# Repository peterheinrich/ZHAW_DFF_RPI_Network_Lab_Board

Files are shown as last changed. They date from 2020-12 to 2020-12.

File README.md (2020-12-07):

# RPI Hands on Networking Lab Board

## Project status: Proof-of-Concept (PoC) success
## !!! THIS IS JUST A PoC !!! Use the provided material and documentation at your own risk!
Known problems:
* The two SATA connectors are a little too close together. While two disks still barely fit, there should be more space in future version.

# General Overview
Welcome to the Git repository of a Raspberry Pi (Compute Module) based networking educational board. Its core features include:
* Three 10/100 Ethernet ports
* A total of 7 USB 2.0 ports:
  * 2x at the front for WiFi adapters
  * 3x internal for USB Drives (simulating RAID 0/1/5)
  * 2x at the back for keyboard and mouse
* Two SATA ports for larger storage (Raid 1)
* Single 12V@2A system supply
* Flexible boot options (SD-Card, USB, Network)
* Raspberry-Pi 40 pin header and mounting options for standard RPI-Hats
* DSI display connector with the same pinout as on Rasperry-Pi-3B boards
* HDMI connector (HDMI out) for external monitors
* CP2102 serial console over USB (microusb device connector) RxD/TxD only!
* ATMega328 (Arduino compatible) system management controller:
  * Power supply monitoring and control (power rail sequencing)
  * System reboot coordination
  * Bootmode selection
  * LVTTL (3.3V) uart for automatic (i.e. remote) board management

Although all peripherals share a single USB2.0 bus and will hence be "slow" to some degree, it should not hamper the learning outcome. 
The purpose of these boards is to provide a self-contained lab environment rather than being small servers. However, in environments where 
speed is not of primary concern, such a system (or systems) could still make a valuable contribution. 

# Fully Open Source / Open Hardware
Everything in this repository is licensed under permissive open source / open hardware licenses.
* License for hardware design documentes (SEE LICENSE_Hardware file): <strong>CERN Open Hardware Licence Version 2 - Permissive</strong>
* License for firmware (SEE LICENSE_Software file): <strong>2-Clause BSD License</strong> 

# Prototype REV-B
SUCCESS! The REV-B prototype is fully operational. Network, display with touch, SATA and all the USB ports are working properly.
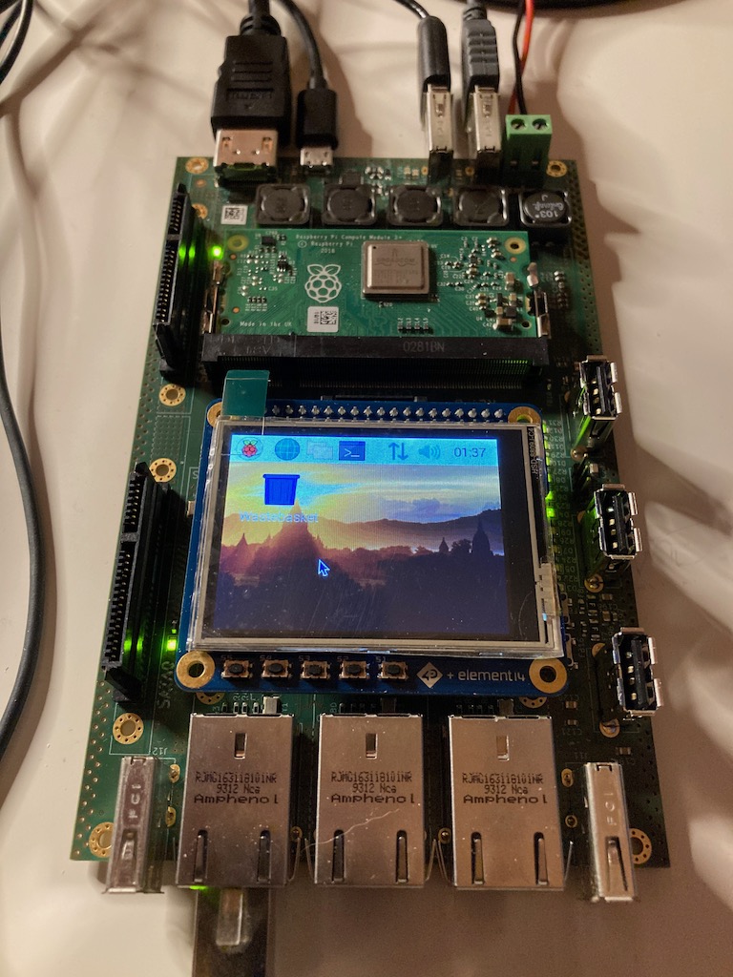
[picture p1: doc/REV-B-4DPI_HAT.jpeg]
Final System With HAT

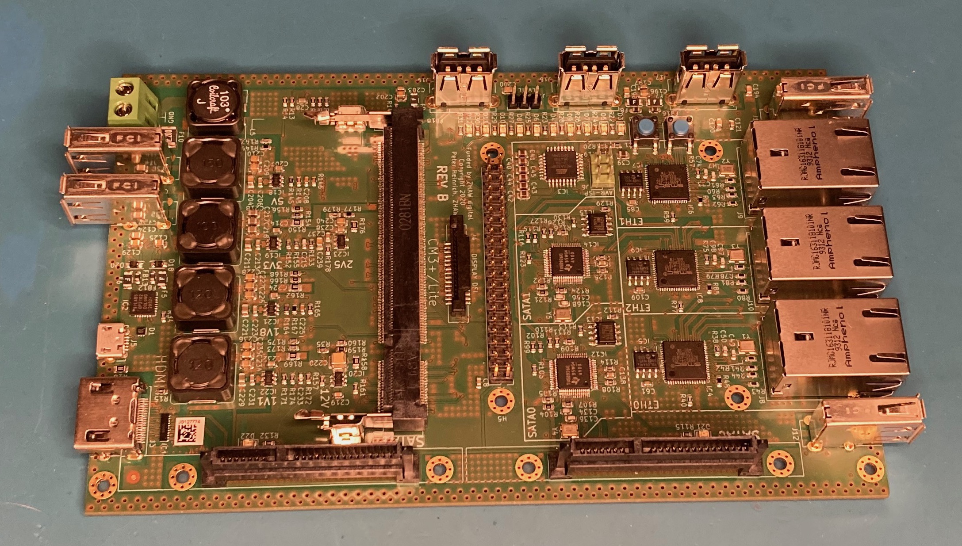
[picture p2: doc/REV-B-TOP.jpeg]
TOP

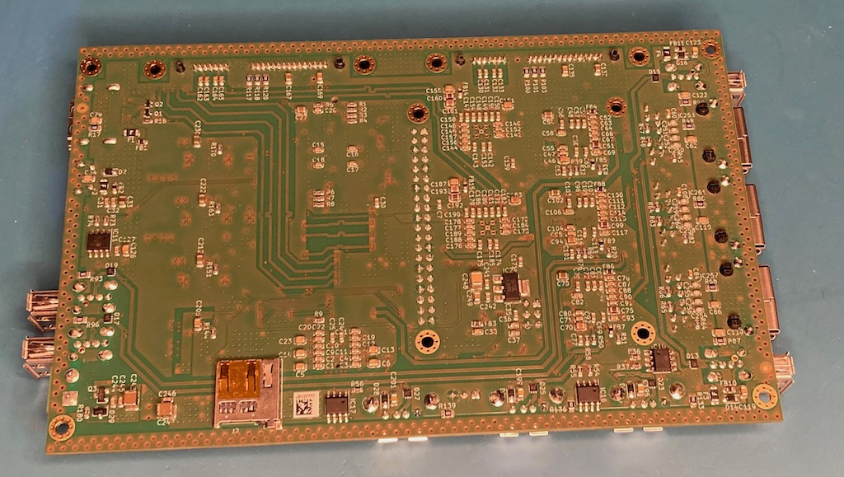
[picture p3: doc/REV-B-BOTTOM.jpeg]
BOTTOM


### System Architecture
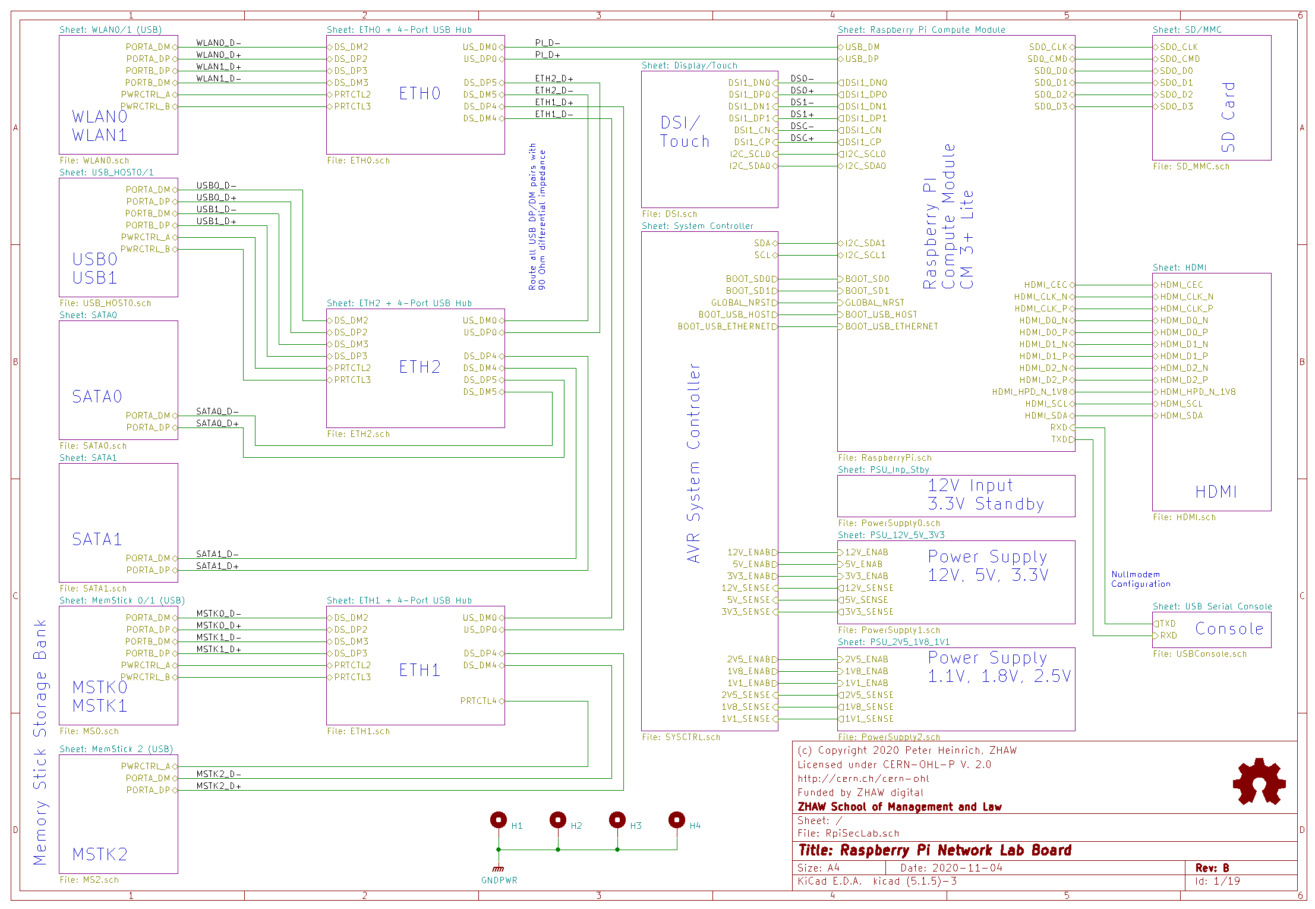
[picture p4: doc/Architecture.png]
Architecture Overview

### Initial PCB Artwork
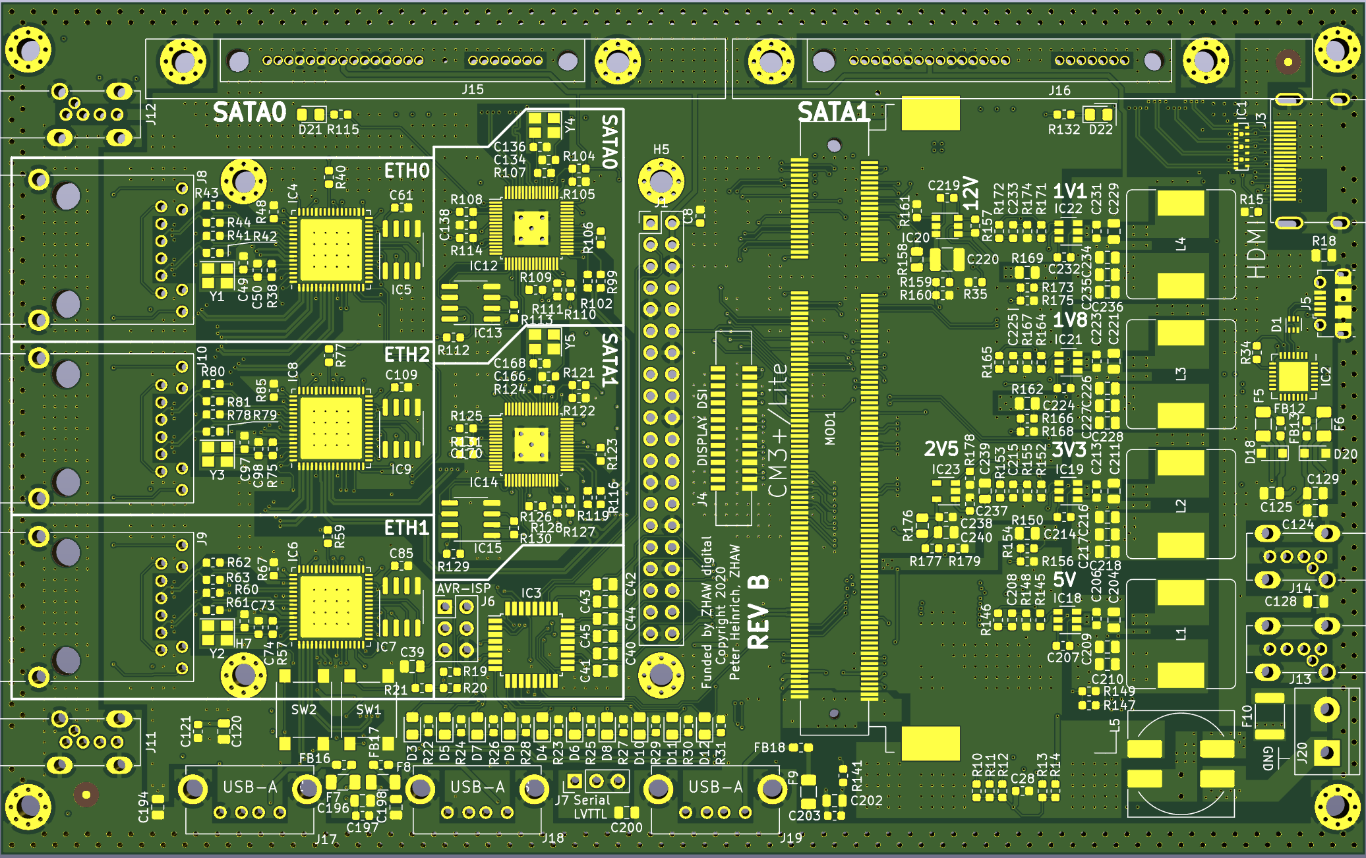
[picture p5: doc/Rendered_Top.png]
PCB Artwork TOP

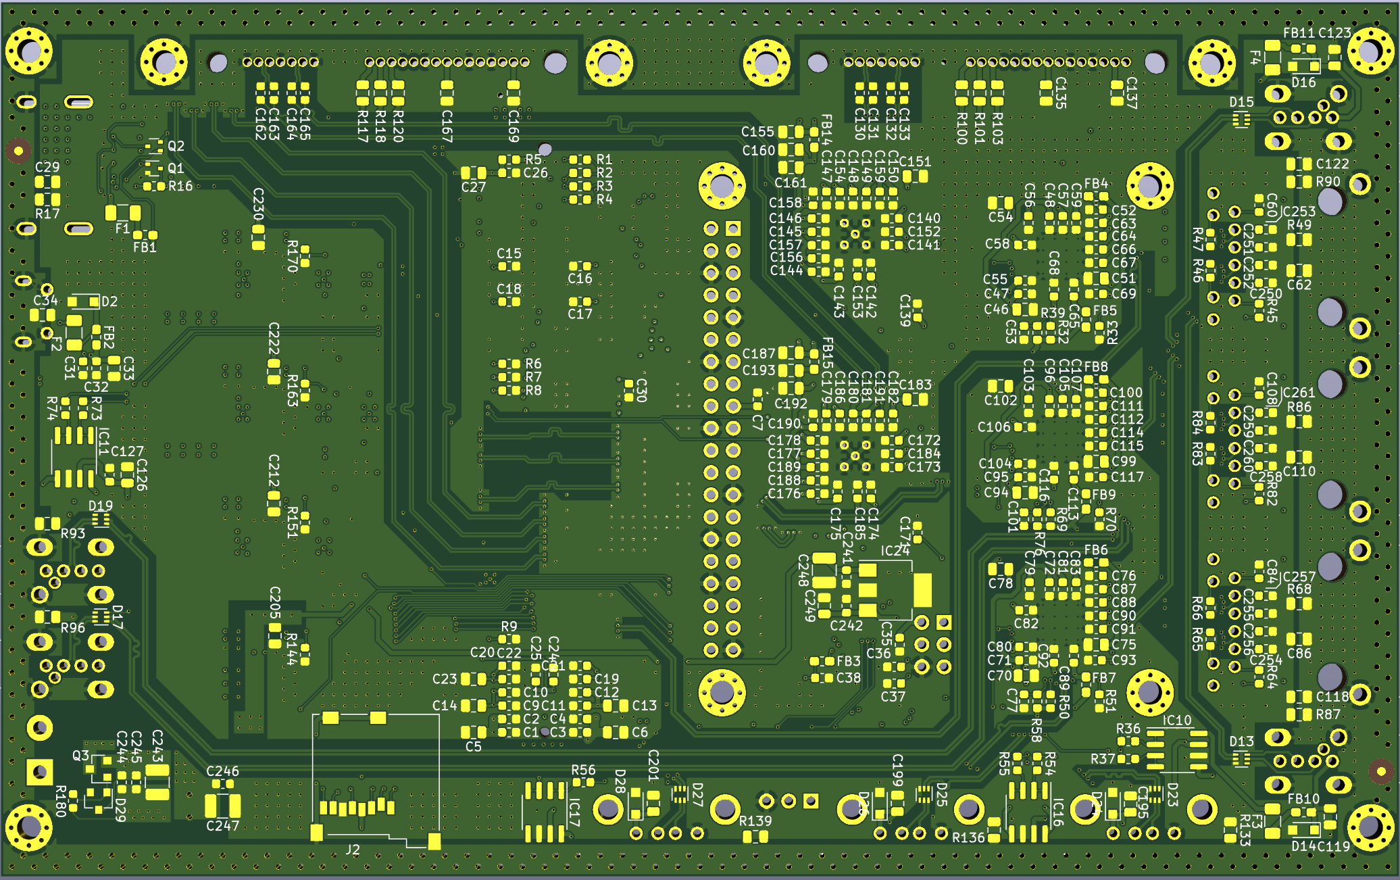
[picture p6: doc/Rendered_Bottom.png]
PCB Artwork BOTTOM


## Prototype REV-A
The project successfully surpassed the revision A proof-of-concept. While its documentation is not included in the repository anymore,
here are some images documenting this project phase:

First time booting Raspbian ...
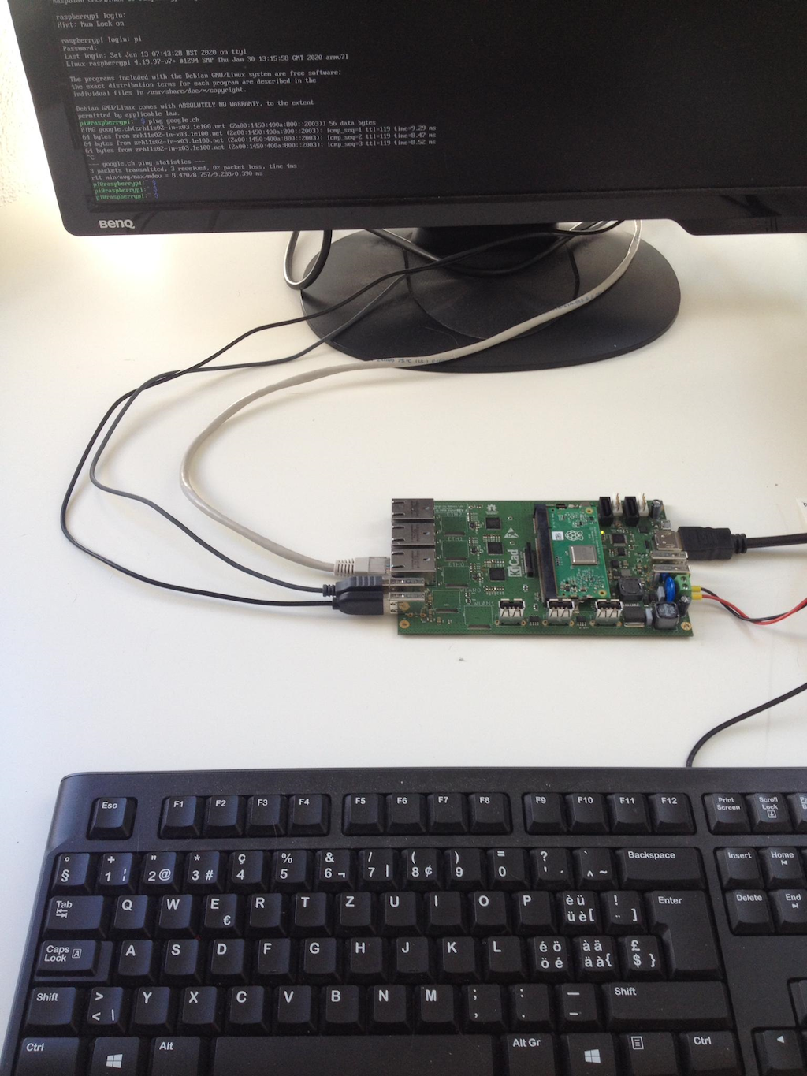
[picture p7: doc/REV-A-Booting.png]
REV-A board booging

Some debugging of network and SATA ...
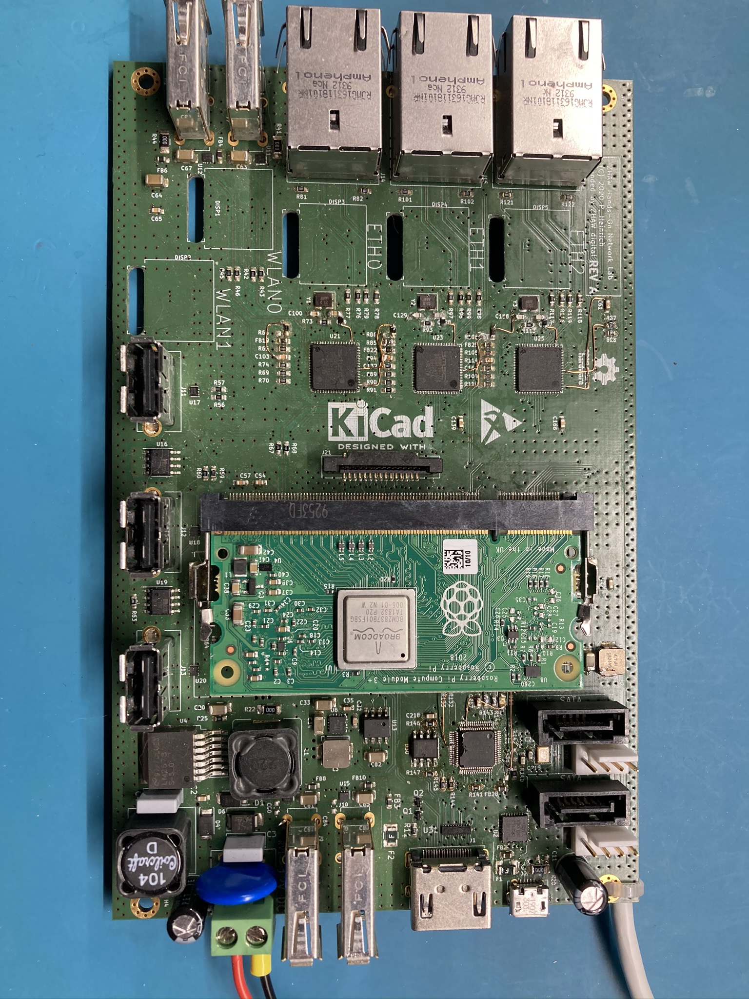
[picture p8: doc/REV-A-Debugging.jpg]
REV-A board debugging

First time successful SATA disk access after finding out that the TI SATA controller only works with some SPI flash chips (i.e. the ones that allow 128 byte page writes with command 0x02).
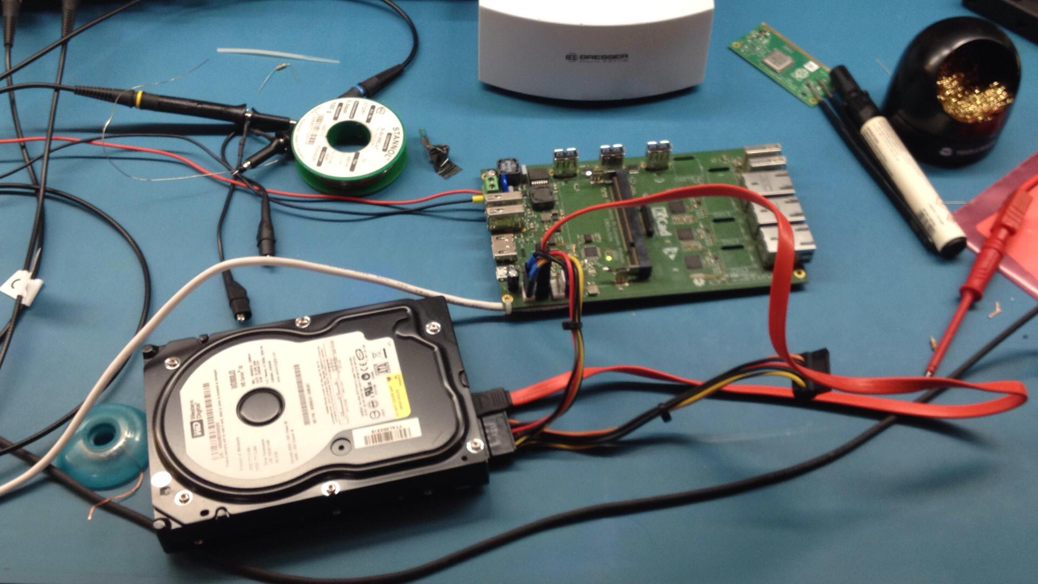
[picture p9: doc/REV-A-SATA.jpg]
REV-A board SATA


# Scenarios
Currently scenarios are developed and will be supplied here later. The initial demonstration scenarios will include:
## Raid Lab
With a single board, students will explore the setup of different raid levels and their behavior under different fault conditions. 
Experiments could cover:
  * Different RAID levels (0/1/5) or even RAID 10 using an additional USB port.
  * Hot spares
  * LVM/LUKS setups
  * System behaviour when disks fail

## HA-Lab
Using three boards, students explore basic high availability concepts.
Experiments could cover:
  * DRBD disk synchronization and cluster file systems
  * Samba active/active setups
  * MySQL active/active replication
  * Round robin DNS load balancing
  
## MitM-Lab (Man-in-the-Middle)
Using three boards students can simulate a two-party communication and an attacker that can eavesdrop / alter the communication.
Experiments could include:
  * ARP spoofing
  * DNS spoofing
  * SSL encryption
  * Mitigation concepts (such as certificate pinning)

## Firewall/IDS-Lab
Using three boards, a typical small firewall setup with an internal and a DMZ zone can be modeled. Students will explore basic
iptables / nftables filtering (IPv4/IPv6), nat (IPv4) setups.

# Acknowledgements
This project received funding from ZHAW digital.

Special thanks to Mirjam Blumenstein, Peter Berlich and Christian Weber for working on the specification and application scenarios. Many thanks to Sami Kjazimi for reviewing my design files and answering my endless questions on electronics design :-)

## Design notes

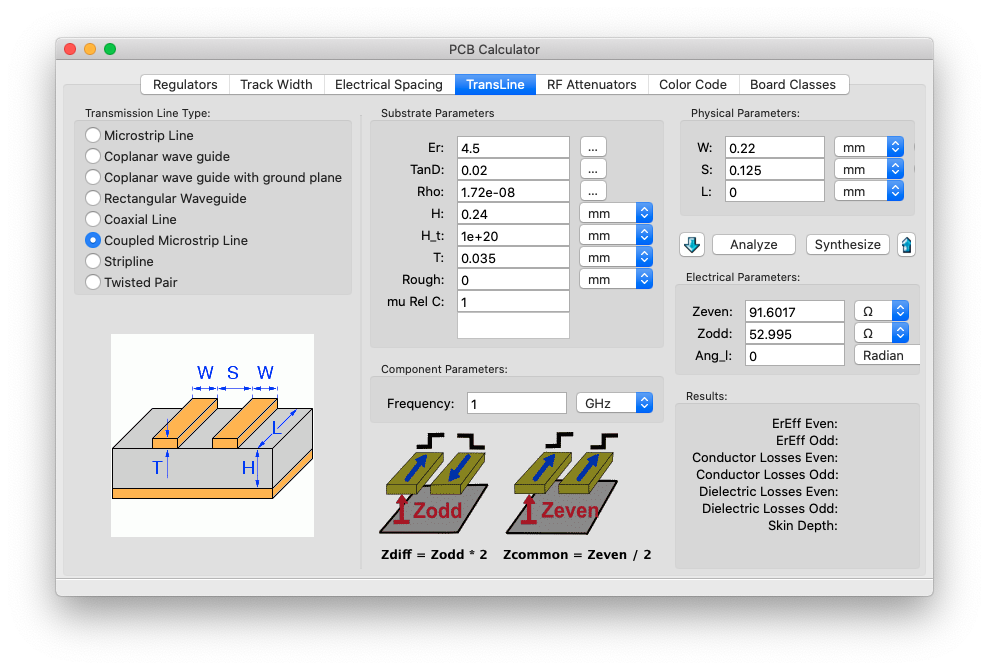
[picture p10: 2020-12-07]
design/100-Ohm-Impedance.png

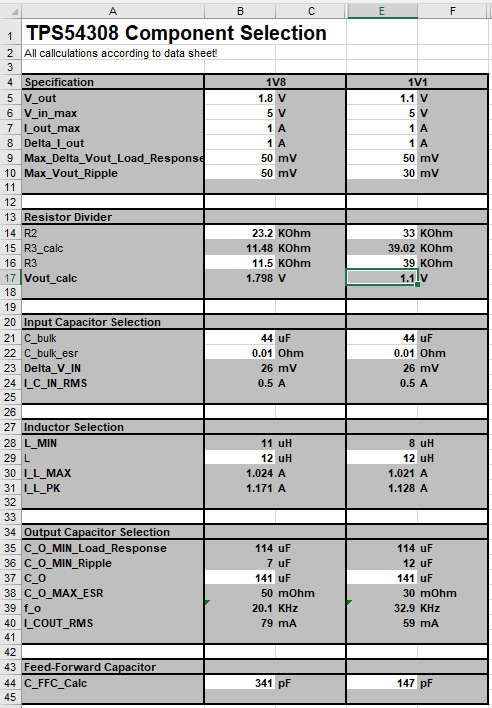
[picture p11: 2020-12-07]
design/TPS54308_1V8_1V1_Calculations.PNG

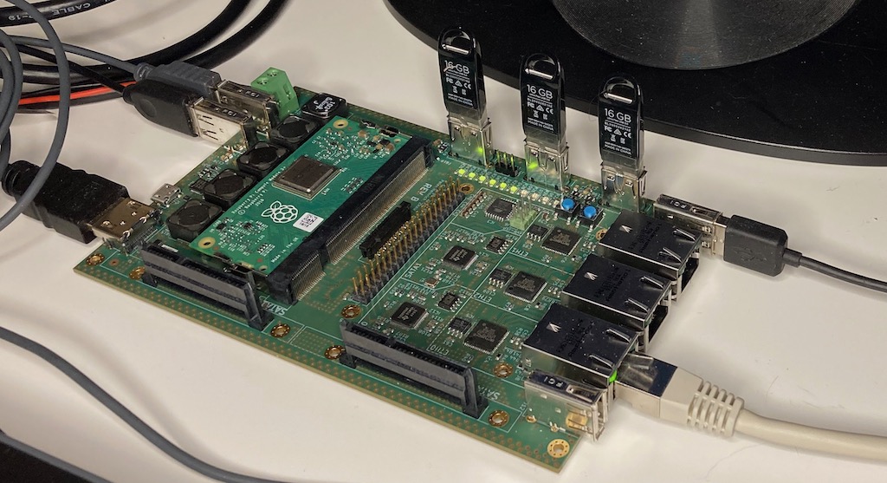
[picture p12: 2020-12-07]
doc/REV-B-DEMO.jpeg

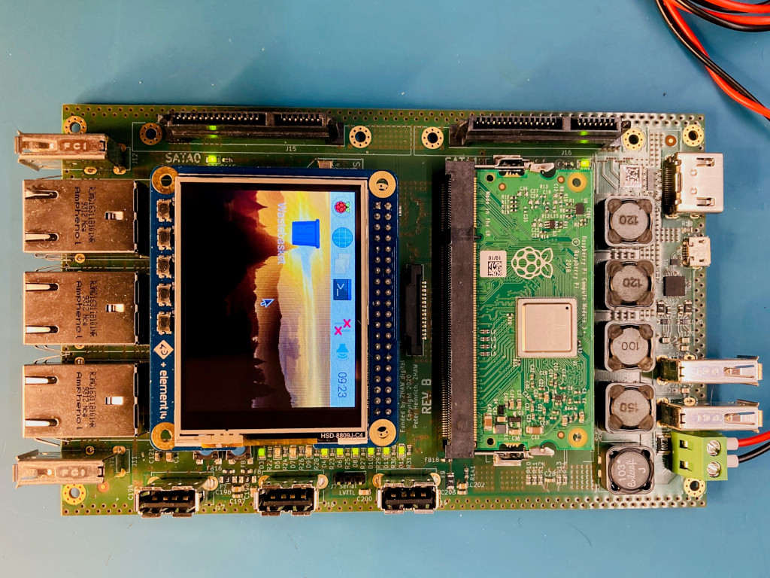
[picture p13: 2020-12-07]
doc/REV-B-TopWithHat.jpg

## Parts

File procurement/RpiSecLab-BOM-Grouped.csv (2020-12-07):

Reference | Quantity | Value | Footprint | Datasheet | MPN | ON_FARNELL | ATTRIBUTE
C130 C131 C132 C133 C162 C163 C164 C165 | 8 | 10n | Capacitor_SMD:C_0603_1608Metric | https://api.kemet.com/component-edge/download/specsheet/C0603C103K1RACTU.pdf | C0603C103K1RACTU | 1865545
C134 C136 C166 C168 | 4 | 33p | Capacitor_SMD:C_0603_1608Metric | https://api.kemet.com/component-edge/download/specsheet/C0603C330J5GACTU.pdf | C0603C330J5GACTU | 1414633
C208 | 1 | 820p | Capacitor_SMD:C_0603_1608Metric | https://api.kemet.com/component-edge/download/specsheet/C0603C821J5RACTU.pdf | C0603C821J5RACTU | 2904785
C215 | 1 | 100p | Capacitor_SMD:C_0603_1608Metric | https://api.kemet.com/component-edge/download/specsheet/C0603C101J5RACTU.pdf | C0603C101J5RACTU | 2773107
C219 C246 C245 | 3 | 1n | Capacitor_SMD:C_0603_1608Metric | http://www.farnell.com/datasheets/2740652.pdf | C0603C102K5RACTU | 1414608 | 50V
C220 C248 | 2 | 47u | Capacitor_SMD:C_1210_3225Metric | http://www.farnell.com/datasheets/2048597.pdf | GRM32EC81C476KE15L | 1907527 | 16V
C225 | 1 | 330p | Capacitor_SMD:C_0603_1608Metric | https://api.kemet.com/component-edge/download/specsheet/C0603C331K5RACTU.pdf | C0603C331K5RACTU | 2429352
C233 | 1 | 150p | Capacitor_SMD:C_0603_1608Metric | http://www.farnell.com/datasheets/1955681.pdf | C0603C151J5GACTU | 1414615
C247 C243 | 2 | 100u | Capacitor_SMD:C_1210_3225Metric | https://api.kemet.com/component-edge/download/specsheet/C1210C107M4PACTU.pdf | C1210C107M4PACTU | 2491298 | 16V
C27 C161 C193 | 3 | 10u | Capacitor_SMD:C_0805_2012Metric | https://api.kemet.com/component-edge/download/specsheet/C0805C106K8RACTU.pdf | C0805C106K8RACTU | 2118132
C29 C34 C62 C86 C110 C122 C118 C128 C124 C198 C194 C200 | 12 | 100n | Capacitor_SMD:C_0805_2012Metric | https://api.kemet.com/component-edge/download/specsheet/C0805C104K5RACTU.pdf | C0805C104K5RACTU | 1414664
C33 C39 C40 C41 C42 C43 C44 C45 C51 C75 C99 C160 C192 | 13 | 1u | Capacitor_SMD:C_0805_2012Metric | https://api.kemet.com/component-edge/download/specsheet/C0805C105K3PACTU.pdf | C0805C105K3PACTU | 1463389
C4 C3 C2 C1 C12 C11 C10 C9 C18 C17 C16 C15 C22 C21 C20 C19 C24 C25 C26 C8 C7 C28 C30 C32 C31 C37 C36 C38 C35 C69 C68 C66 C65 C64 C63 C59 C58 C57 C56 C55 C52 C53 C48 C47 C61 C67 C93 C92 C91 C90 C89 C88 C87 C83 C82 C81 C80 C79 C76 C77 C72 C71 C85 C117 C116 C115 C114 C113 C112 C111 C107 C106 C105 C104 C103 C100 C101 C96 C95 C109 C121 C127 C140 C141 C142 C143 C144 C145 C146 C147 C148 C149 C150 C152 C153 C154 C156 C157 C158 C159 C139 C138 C172 C173 C174 C175 C176 C177 C178 C179 C180 C181 C182 C184 C185 C186 C188 C189 C190 C191 C171 C170 C197 C203 C207 C206 C214 C213 C237 C238 C224 C223 C232 C231 C244 C241 C242 | 137 | 100n | Capacitor_SMD:C_0603_1608Metric | https://api.kemet.com/component-edge/download/specsheet/C0603C104M4RACTU.pdf | C0603C104M4RACTU | 2581045 | 16V
C46 C70 C94 C151 C135 C137 C183 C167 C169 | 9 | 4u7 | Capacitor_SMD:C_0805_2012Metric | http://www.farnell.com/datasheets/2079186.pdf | GRM21BR61H475KE51L | 2611942 | 50V
C49 C50 C250 C253 C251 C252 C73 C74 C254 C257 C255 C256 C97 C98 C258 C261 C259 C260 | 18 | 15p | Capacitor_SMD:C_0603_1608Metric | https://api.kemet.com/component-edge/download/specsheet/C0603C475K8PACTU.pdf | C0603C150J5GACTU | 1414614
C5 C6 C13 C14 C23 C119 C123 C120 C125 C129 C126 C155 C187 C195 C199 C196 C201 C202 C209 C210 C204 C205 C240 C239 C227 C228 C226 C235 C236 C234 C249 | 31 | 47u | Capacitor_SMD:C_0805_2012Metric | http://www.farnell.com/datasheets/2047835.pdf | GRM21BR60J476ME15L | 2362109
C54 C78 C102 C216 C217 C211 C218 C212 C221 C229 C230 C222 | 12 | 22u | Capacitor_SMD:C_0805_2012Metric | https://api.kemet.com/component-edge/download/specsheet/C0805C226M9PACTU.pdf | C0805C226M9PACTU | 1108326
C60 C84 C108 | 3 | 22n | Capacitor_SMD:C_0603_1608Metric | https://api.kemet.com/component-edge/download/specsheet/C0603C475K8PACTU.pdf | C0603C223K1RACTU | 1865548
D1 D13 D15 D17 D19 D23 D25 D27 | 8 | ECMF02-2AMX6 | Package_DFN_QFN:ST_UQFN-6L_1.5x1.7mm_Pitch0.5mm | https://www.st.com/resource/en/datasheet/ecmf02-2amx6.pdf | ECMF02-2AMX6 | 2629720
D2 D14 D16 D18 D20 D24 D26 D28 | 8 | PESD5V0L1BA | Diode_SMD:D_SOD-323_HandSoldering | http://www.farnell.com/datasheets/682594.pdf | PESD5V0L1BA,115 | 8737606
D29 | 1 | 14V | Diode_SMD:D_SOT-23_ANK | http://www.farnell.com/datasheets/2236794.pdf | MMBZ5244BLT1G | 2844829
D3 D5 D7 D9 D4 D6 D8 D10 D11 D12 D21 D22 | 12 | LED | LED_SMD:LED_0805_2012Metric_Pad1.15x1.40mm_HandSolder | http://www.farnell.com/datasheets/1854080.pdf | KP-2012LSGC | 2463991
F1 F2 F3 F4 F5 F6 F7 F8 F9 | 9 | 500mA | Fuse:Fuse_1206_3216Metric | http://www.littelfuse.com/data/en/Data_Sheets/Littelfuse_PTC_1206L.pdf | 1206L050YR | 1596993
F10 | 1 | 2A | Fuse:Fuse_1812_4532Metric | https://www.farnell.com/datasheets/578288.pdf | 1812L200THPR | 1822216
FB1 FB2 FB3 FB4 FB5 FB6 FB7 FB8 FB9 FB10 FB11 FB12 FB13 FB14 FB15 FB16 FB17 FB18 | 18 | 2.0A | Inductor_SMD:L_0603_1608Metric_Pad1.05x0.95mm_HandSolder | http://www.farnell.com/datasheets/1740433.pdf | BLM18PG121SN1D | 1515738
IC1 | 1 | ESD8040 | ESD8040:ESD8040 | http://www.farnell.com/datasheets/2355017.pdf | ESD8040MUTAG | 2533264
IC10 IC11 IC16 IC17 | 4 | MIC2026-1YM | Package_SO:SOIC-8_3.9x4.9mm_P1.27mm | http://www.farnell.com/datasheets/712329.pdf | MIC2026-1YM | 2509897
IC12 IC14 | 2 | TUSB9261IPVP | TUSB9261IPVP:PQFP-64_7x7mm_P0.4mm | https://www.ti.com/lit/ds/symlink/tusb9261.pdf | TUSB9261IPVP | 3124773
IC13 IC15 | 2 | IS25LQ010B | Package_SO:SOIC-8_3.9x4.9mm_P1.27mm | http://www.farnell.com/datasheets/1669409.pdf | IS25LQ010B-JNLE | 2901147
IC19 IC18 IC22 IC21 | 4 | TPS54308 | Package_TO_SOT_SMD:SOT-23-6 | https://www.ti.com/lit/ds/symlink/tps54308.pdf | TPS54308DDCT | 3007333
IC2 | 1 | CP2102-GM | Package_DFN_QFN:QFN-28-1EP_5x5mm_P0.5mm_EP3.35x3.35mm | http://www.farnell.com/datasheets/2167291.pdf | CP2102-GM | 9282130
IC20 | 1 | FDC6330L | FDC6330L:FDC6330L | https://www.onsemi.com/pub/Collateral/FDC6330L-D.PDF | FDC6330L | 9844864
IC23 | 1 | NCP718ASN250 | Package_TO_SOT_SMD:SOT-23-5 | http://www.farnell.com/datasheets/2711392.pdf | NCP718ASN250T1G | 2981161
IC24 | 1 | LM2937IMP-3.3 | Package_TO_SOT_SMD:SOT-223-3_TabPin2 | https://www.ti.com/lit/ds/symlink/lm2937.pdf | LM2937IMP-3.3/NOPB | 3122675
IC3 | 1 | ATMEGA328P-AU | Package_QFP:TQFP-32_7x7mm_P0.8mm | http://ww1.microchip.com/downloads/en/DeviceDoc/ATmega48A-PA-88A-PA-168A-PA-328-P-DS-DS40002061A.pdf | ATMEGA328P-AU | 1715486
IC4 IC6 IC8 | 3 | LAN9514-JZX-TR | LAN9514-JZX-TR:QFN-64-1EP_9x9mm_P0.5mm_EP7.15x7.15mm_ThermalVias | http://ww1.microchip.com/downloads/en/devicedoc/00002306a.pdf | LAN9514-JZX-TR | 3131908
IC5 IC7 IC9 | 3 | 93LC66A-I_SN | Package_SO:SOIC-8_3.9x4.9mm_P1.27mm | https://www.mouser.ch/datasheet/2/268/21795b-75092.pdf | 93LC66A-I_SN | 2851654
J1 | 1 | Conn_RPi | Connector_PinHeader_2.54mm:PinHeader_2x20_P2.54mm_Vertical | https://www.molex.com/webdocs/datasheets/pdf/en-us/0010897402_PCB_HEADERS.pdf | 10-89-7402 | 2396214
J12 J11 J13 J14 | 4 | Conn_USB_A | 73725-0110BLF:73725-0110BLF | http://www.farnell.com/cad/2562142.pdf | 73725-0110BLF | 2112380
J15 J16 | 2 | Conn_SATA | 87678-1001:87678-1001 | http://www.farnell.com/datasheets/2832428.pdf | 87678-1001 | 3226185
J17 J18 J19 | 3 | Conn_USB_A | 1734366-1:1734366-1 | http://www.farnell.com/datasheets/1650952.pdf | 1734366-1 | 1654064
J2 | 1 | Conn_Micro_SD_Card | 693071010811:693071010811 | http://katalog.we-online.de/datasheet/693071010811.pdf | 693071010811 | 2081363
J20 | 1 | Conn_DC_Supply | TerminalBlock:TerminalBlock_bornier-2_P5.08mm | http://www.newark.com/pdfs/datasheets/spc/Ta-987.pdf | MC24366 | 2396251
J3 | 1 | Conn_HDMI_A | 47151-1051:47151-1051 | http://www.farnell.com/datasheets/2696868.pdf | 47151-1051 | 2614936
J4 | 1 | Conn_DISPLAY | 1-1734248-5:1-1734248-5 | http://www.farnell.com/datasheets/1838449.pdf | 1-1734248-5 | 2890893
J5 | 1 | Conn_USB_B_Micro | Connector_USB:USB_Micro-B_Molex-105017-0001 | http://www.farnell.com/datasheets/2693980.pdf | 105017-0001 | 2293836
J6 | 1 | Conn_AVR_ISP_6P | Connector_PinHeader_2.54mm:PinHeader_2x03_P2.54mm_Vertical | http://www.farnell.com/datasheets/38081.pdf | 826942-3 | 1248159
J7 | 1 | Conn_01x03_Male | Connector_PinHeader_2.54mm:PinHeader_1x03_P2.54mm_Vertical | http://www.farnell.com/datasheets/32535.pdf | 826629-3 | 3418297
J8 J9 J10 | 3 | Conn_RJ45_MAG | RJMG163118101NR:RJMG163118101NR | http://www.farnell.com/cad/2577820.pdf | RJMG163118101NR | 1357436
L1 | 1 | 15uH | Inductor_SMD:L_Bourns_SRR1260 | https://www.bourns.com/docs/Product-Datasheets/SRR1260.pdf | SRR1260-150M | 2113015
L2 | 1 | 10uH | Inductor_SMD:L_Bourns_SRR1260 | https://www.bourns.com/docs/Product-Datasheets/SRR1260.pdf | SRR1260-100M | 2212501
L3 L4 | 2 | 12uH | Inductor_SMD:L_Bourns_SRR1260 | https://www.bourns.com/docs/Product-Datasheets/SRR1260.pdf | SRR1260-120M | 2859155
L5 | 1 | MSD1260-103MLB | MSD1260-103MLB:MSD1260-103MLB | https://www.coilcraft.com/getmedia/79bacbf1-ec2a-4e20-9b30-12448424231b/msd1260.pdf | MSD1260-103MLB | 2288031
MOD1 | 1 | CM3+Lite Connector | 1612618-4:1612618-4 | http://www.farnell.com/datasheets/1794089.pdf | 1612618-4 | 2396418
Q2 Q1 | 2 | DMG1012T | SOT-532:SOT-532 | http://www.farnell.com/datasheets/2040092.pdf | DMG1012T-7 | 2543524
Q3 | 1 | Si2319CDS | Package_TO_SOT_SMD:SOT-23 | http://www.farnell.com/datasheets/2049359.pdf | SI2319CDS-T1-GE3 | 1858942
R104 R121 | 2 | 90K9 | Resistor_SMD:R_0603_1608Metric | https://www.vishay.com/docs/20035/dcrcwe3.pdf | CRCW060390K9FKEA | 2138493
R145 R168 | 2 | 20K | Resistor_SMD:R_0603_1608Metric | https://www.vishay.com/docs/20035/dcrcwe3.pdf | CRCW060320K0FKEA | 1469774
R148 | 1 | 2K7 | Resistor_SMD:R_0603_1608Metric | https://www.vishay.com/docs/20035/dcrcwe3.pdf | CRCW06032K70FKEA | 1469768
R149 R177 | 2 | 3K | Resistor_SMD:R_0603_1608Metric | https://www.vishay.com/docs/20035/dcrcwe3.pdf | CRCW06033K00FKEA | 1469790
R152 | 1 | 68K | Resistor_SMD:R_0603_1608Metric | https://www.vishay.com/docs/20035/dcrcwe3.pdf | CRCW060368K0FKEA | 1469832
R153 R146 R172 R165 | 4 | 2K2 | Resistor_SMD:R_0603_1608Metric | https://www.vishay.com/docs/20035/dcrcwe3.pdf | CRCW06032K20FKEA | 2122405
R154 | 1 | 62K | Resistor_SMD:R_0603_1608Metric | https://www.vishay.com/docs/20035/dcrcwe3.pdf | CRCW060362K0FKEA | 2138478
R155 | 1 | 15K | Resistor_SMD:R_0603_1608Metric | https://www.vishay.com/docs/20035/dcrcwe3.pdf | CRCW060315K0FKEA | 1469758
R156 | 1 | 27K | Resistor_SMD:R_0603_1608Metric | https://www.vishay.com/docs/20035/dcrcwe3.pdf | CRCW060327K0FKEA | 1652864
R157 R161 | 2 | 4K7 | Resistor_SMD:R_0603_1608Metric | https://www.vishay.com/docs/20035/dcrcwe3.pdf | CRCW06034K70FKEA | 1469807
R159 | 1 | 22K | Resistor_SMD:R_0603_1608Metric | https://www.vishay.com/docs/20035/dcrcwe3.pdf | CRCW060322K0FKEA | 1469779
R16 R15 R144 R151 R35 R178 R163 R170 | 8 | 100K | Resistor_SMD:R_0603_1608Metric | https://www.vishay.com/docs/20035/dcrcwe3.pdf | CRCW0603100KFKEA | 1469649
R160 R179 | 2 | 2K | Resistor_SMD:R_0603_1608Metric | https://www.vishay.com/docs/20035/dcrcwe3.pdf | CRCW06032K00FKEA | 1469764
R164 | 1 | 23K2 | Resistor_SMD:R_0603_1608Metric | https://www.vishay.com/docs/20035/dcrcwe3.pdf | CRCW060323K2FKEA | 1652861
R166 | 1 | 16K | Resistor_SMD:R_0603_1608Metric | https://www.vishay.com/docs/20035/dcrcwe3.pdf | CRCW060316K0FKEA | 2138433
R167 | 1 | 11K5 | Resistor_SMD:R_0603_1608Metric | https://www.vishay.com/docs/20035/dcrcwe3.pdf | CRCW060311K5FKEA | 1469753
R17 R18 R49 R68 R86 R90 R87 R96 R93 R100 R101 R103 R117 R118 R120 R136 R133 R139 R150 R158 R176 R162 R169 | 23 | 0R | Resistor_SMD:R_0805_2012Metric | https://www.vishay.com/docs/20035/dcrcwe3.pdf | CRCW08050000Z0EA | 1469846
R171 | 1 | 33K | Resistor_SMD:R_0603_1608Metric | https://www.vishay.com/docs/20035/dcrcwe3.pdf | CRCW060333K0FKEA | 1469801
R174 | 1 | 39K | Resistor_SMD:R_0603_1608Metric | https://www.vishay.com/docs/20035/dcrcwe3.pdf | CRCW060339K0FKEA | 1469804
R180 | 1 | 3K3 | Resistor_SMD:R_0603_1608Metric | https://www.vishay.com/docs/20035/dcrcwe3.pdf | CRCW06033K30FKEA | 1469793
R22 R24 R26 R28 R23 R25 R27 R29 R30 R31 R173 | 11 | 1K | Resistor_SMD:R_0603_1608Metric | https://www.vishay.com/docs/20035/dcrcwe3.pdf | CRCW06031K00FKEA | 1469740
R32 R50 R69 | 3 | 680 | Resistor_SMD:R_0603_1608Metric | https://www.vishay.com/docs/20035/dcrcwe3.pdf | CRCW0603680RFKEA | 1469834
R33 R51 R70 R147 | 4 | 12K | Resistor_SMD:R_0603_1608Metric | https://www.vishay.com/docs/20035/dcrcwe3.pdf | CRCW060312K0FKEA | 1652834
R38 R57 R75 R107 R124 | 5 | 1M | Resistor_SMD:R_0603_1608Metric | https://www.vishay.com/docs/20035/dcrcwe3.pdf | CRCW06031M00FKEA | 1469746
R41 R42 R43 R44 R60 R61 R62 R63 R78 R79 R80 R81 | 12 | 49R9 | Resistor_SMD:R_0603_1608Metric | https://www.vishay.com/docs/20035/dcrcwe3.pdf | CRCW060349R9FKEA | 1469817
R45 R64 R82 | 3 | 10R | Resistor_SMD:R_0603_1608Metric | https://www.vishay.com/docs/20035/dcrcwe3.pdf | CRCW060310R0FKEA | 1469751
R46 R47 R36 R37 R65 R66 R54 R55 R56 R83 R84 R73 R74 R115 R132 | 15 | 330 | Resistor_SMD:R_0603_1608Metric | https://www.vishay.com/docs/20035/dcrcwe3.pdf | CRCW0603330RFKEA | 1469803
R48 R67 R85 | 3 | 12K4 | Resistor_SMD:R_0603_1608Metric | https://www.vishay.com/docs/20035/dcrcwe3.pdf | CRCW060312K4FKEA | 1652836
R5 R102 R99 R119 R116 | 5 | 0R | Resistor_SMD:R_0603_1608Metric | https://www.vishay.com/docs/20035/dcrcwe3.pdf | CRCW06030000Z0EA | 1469739
R9 R1 R2 R3 R4 R6 R7 R8 R10 R11 R12 R13 R14 R34 R21 R19 R20 R39 R40 R58 R59 R76 R77 R112 R113 R106 R105 R111 R110 R108 R109 R114 R129 R130 R123 R122 R128 R127 R125 R126 R131 R141 R175 | 43 | 10K | Resistor_SMD:R_0603_1608Metric | https://www.vishay.com/docs/20035/dcrcwe3.pdf | CRCW060310K0FKEA | 1469748
SW1 | 1 | SW_Boot_Select | Button_Switch_SMD:SW_Push_1P1T_NO_6x6mm_H9.5mm | http://www.farnell.com/datasheets/2706291.pdf | PTS645SM43SMTR92LFS | 2320087
SW2 | 1 | SW_RESET | Button_Switch_SMD:SW_Push_1P1T_NO_6x6mm_H9.5mm | http://www.farnell.com/datasheets/2706291.pdf | PTS645SM43SMTR92LFS | 2320087
Y1 Y2 Y3 | 3 | 25MHz | Crystal:Crystal_SMD_Abracon_ABM8G-4Pin_3.2x2.5mm | http://www.farnell.com/datasheets/1853066.pdf | LFXTAL055299 | 2449505
Y4 Y5 | 2 | 40MHz | Crystal:Crystal_SMD_Abracon_ABM8G-4Pin_3.2x2.5mm | http://www.farnell.com/datasheets/2792510.pdf | ABM8-40.000MHZ-10-D1G-T | 3228516

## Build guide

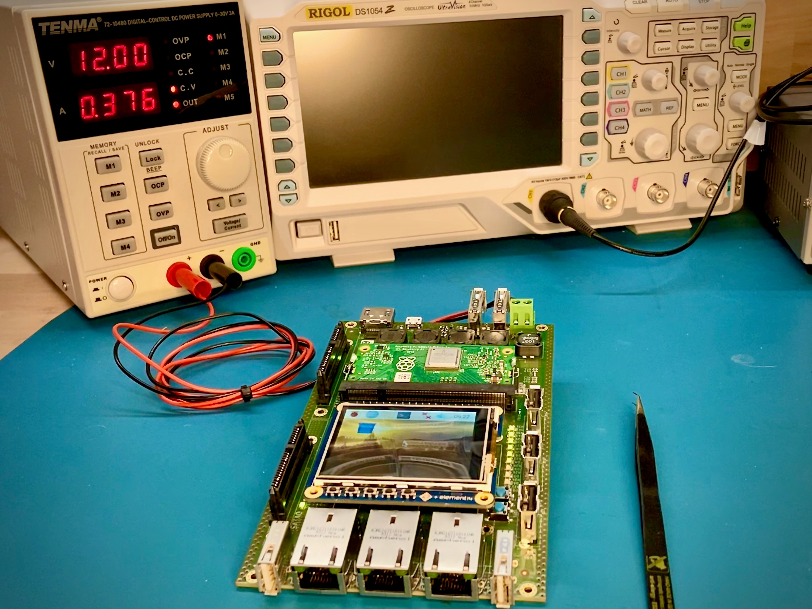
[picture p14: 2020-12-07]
doc/REV-B-LabSetup.jpg

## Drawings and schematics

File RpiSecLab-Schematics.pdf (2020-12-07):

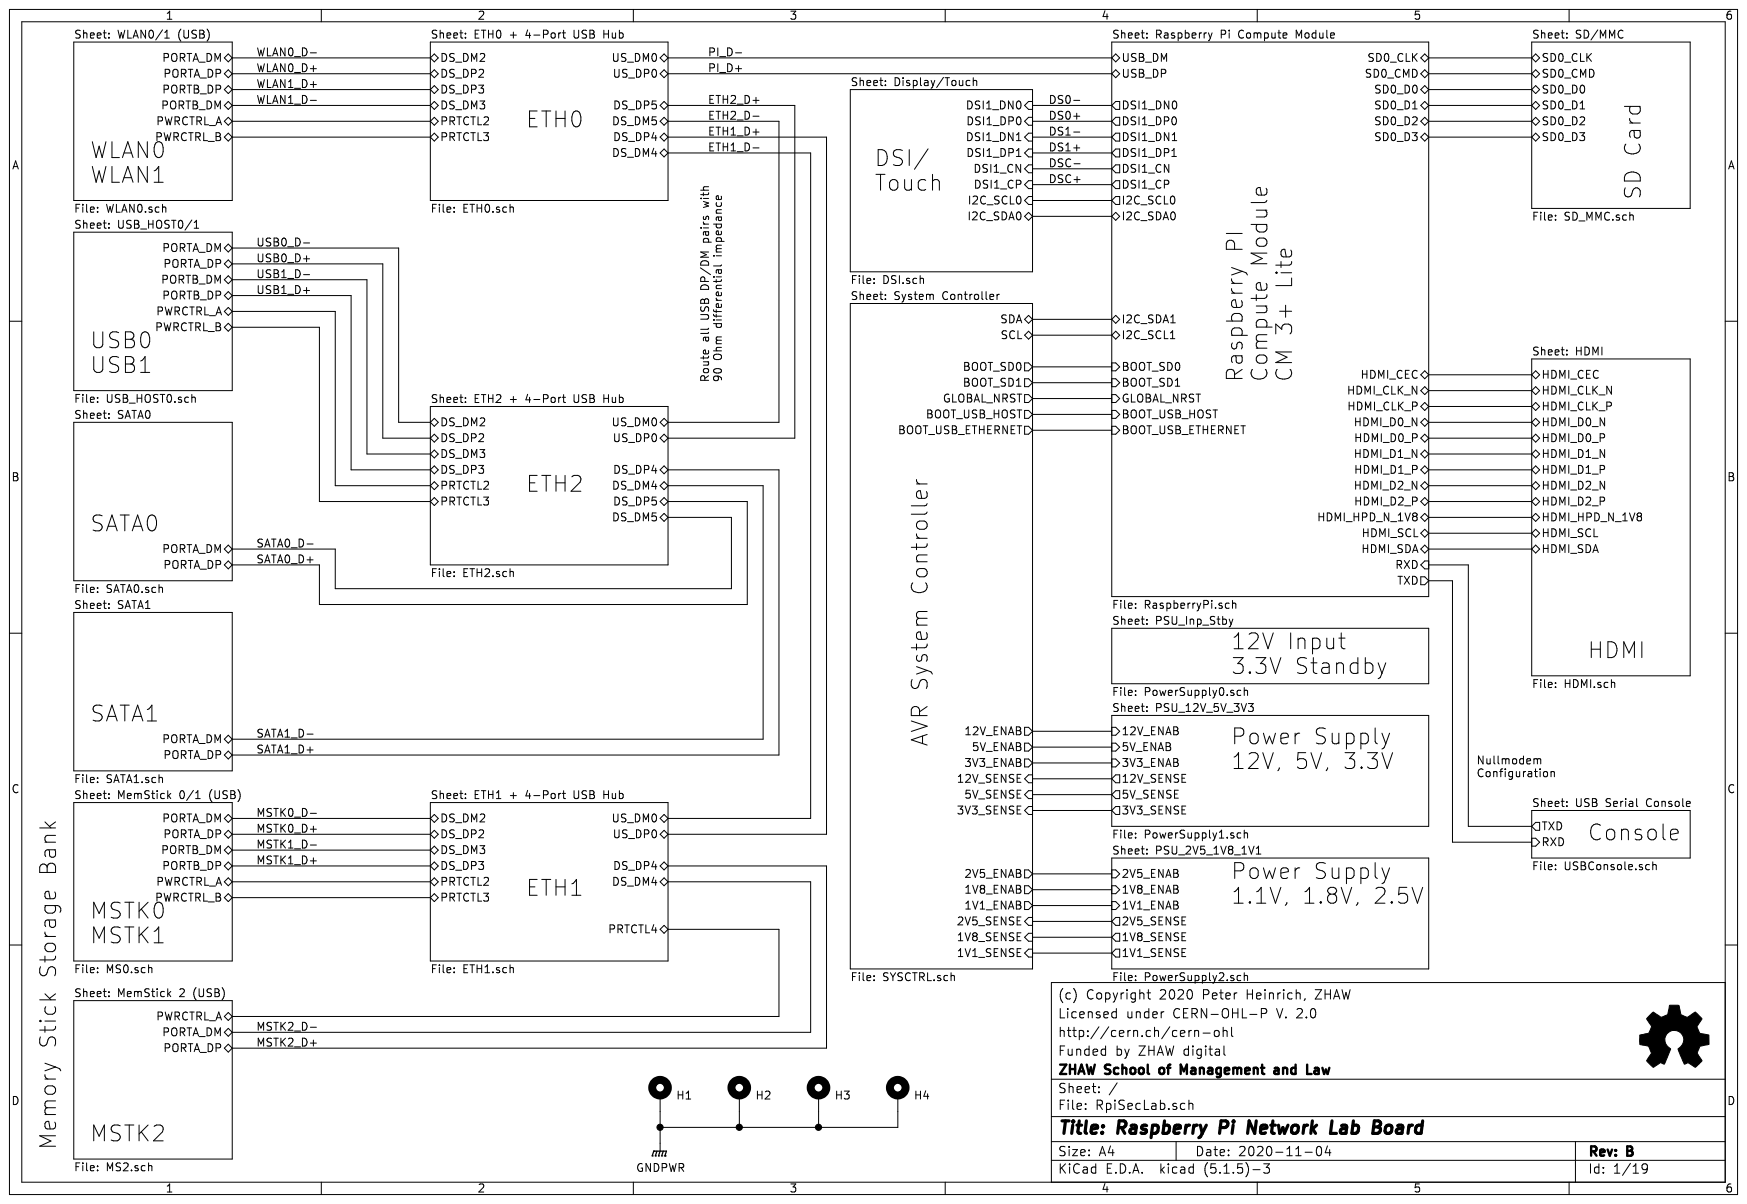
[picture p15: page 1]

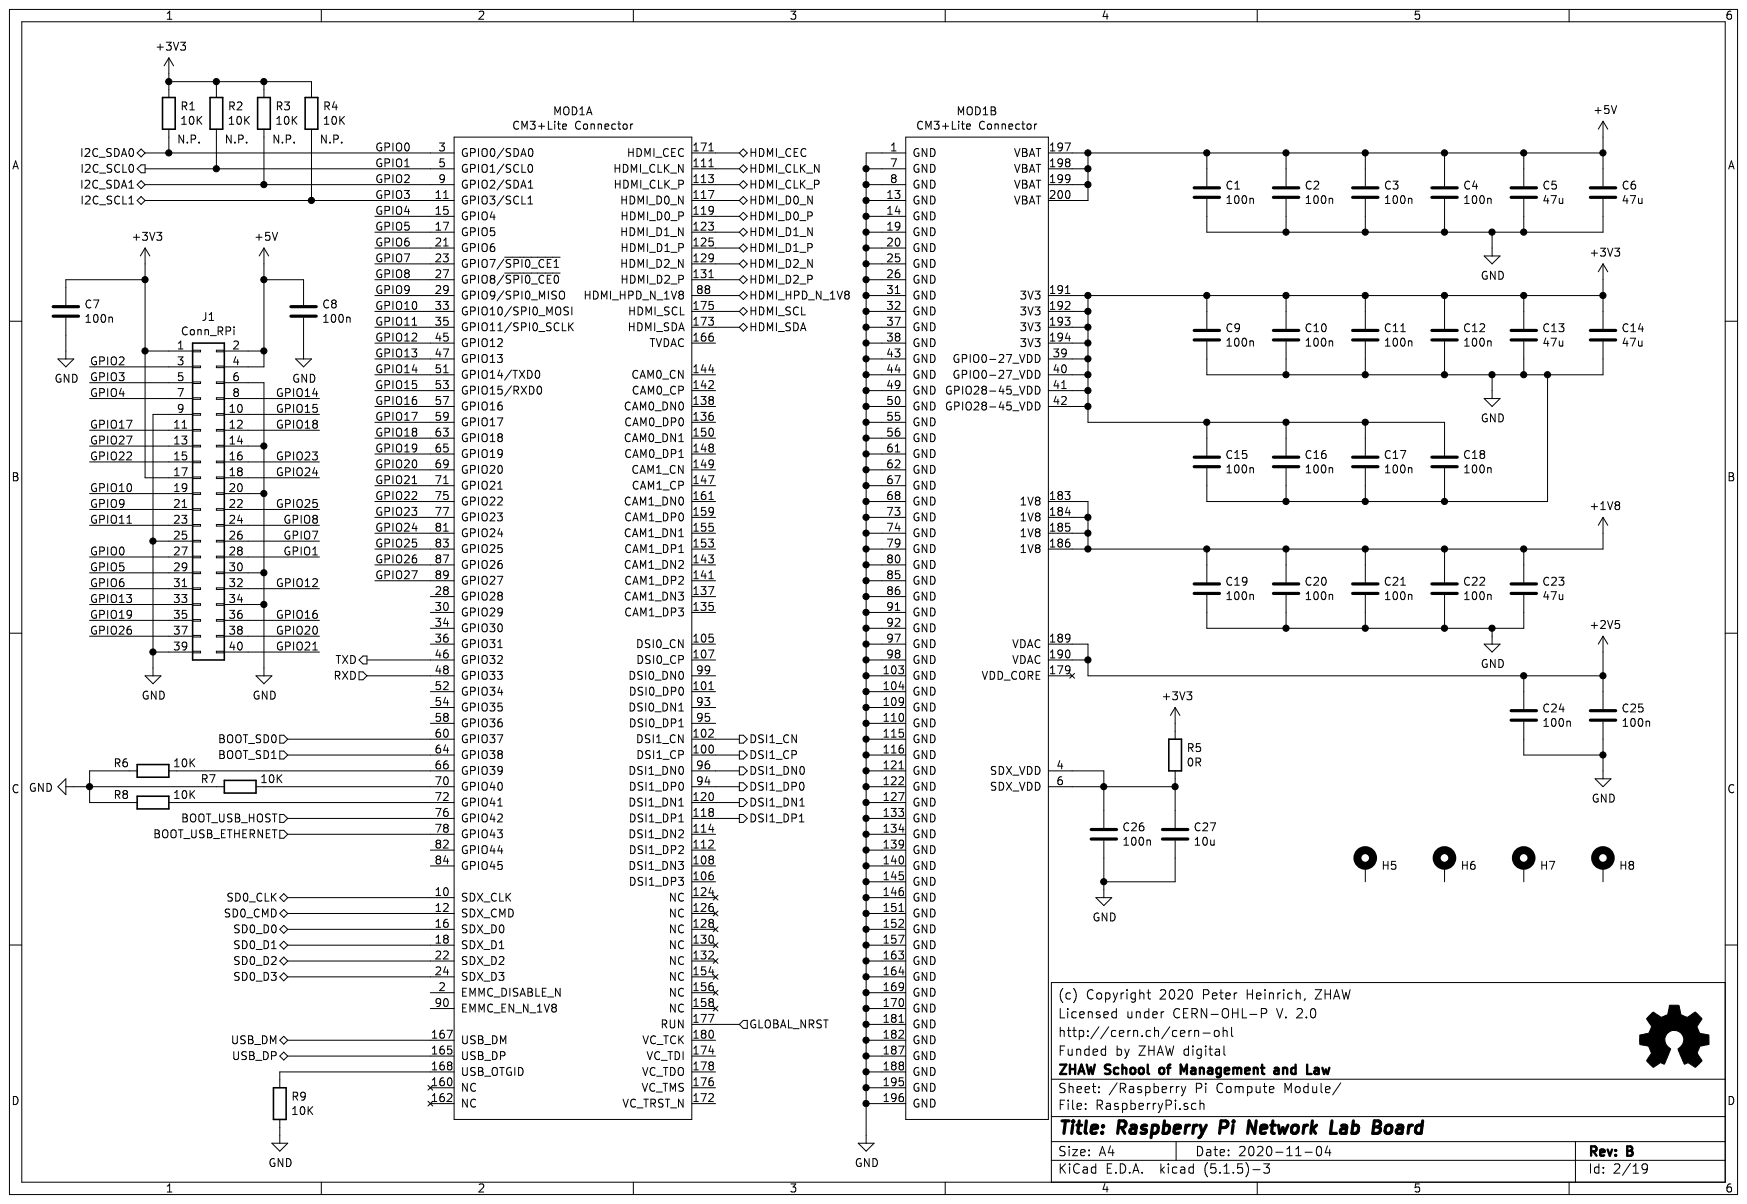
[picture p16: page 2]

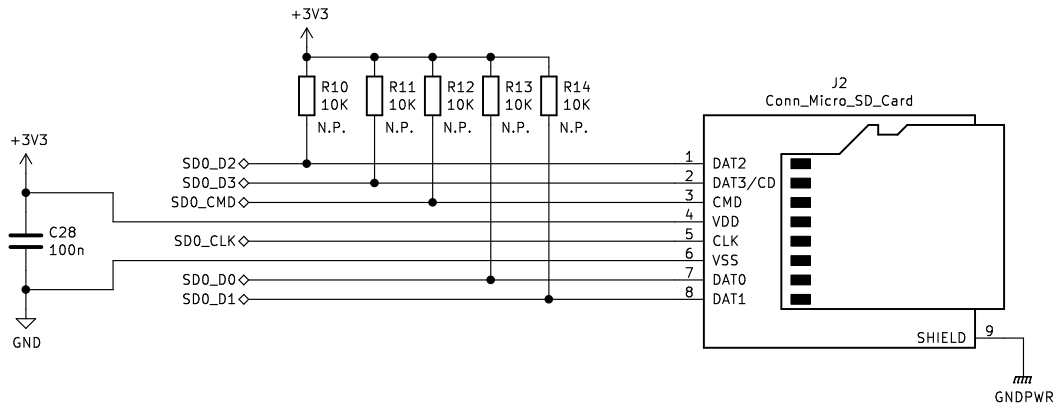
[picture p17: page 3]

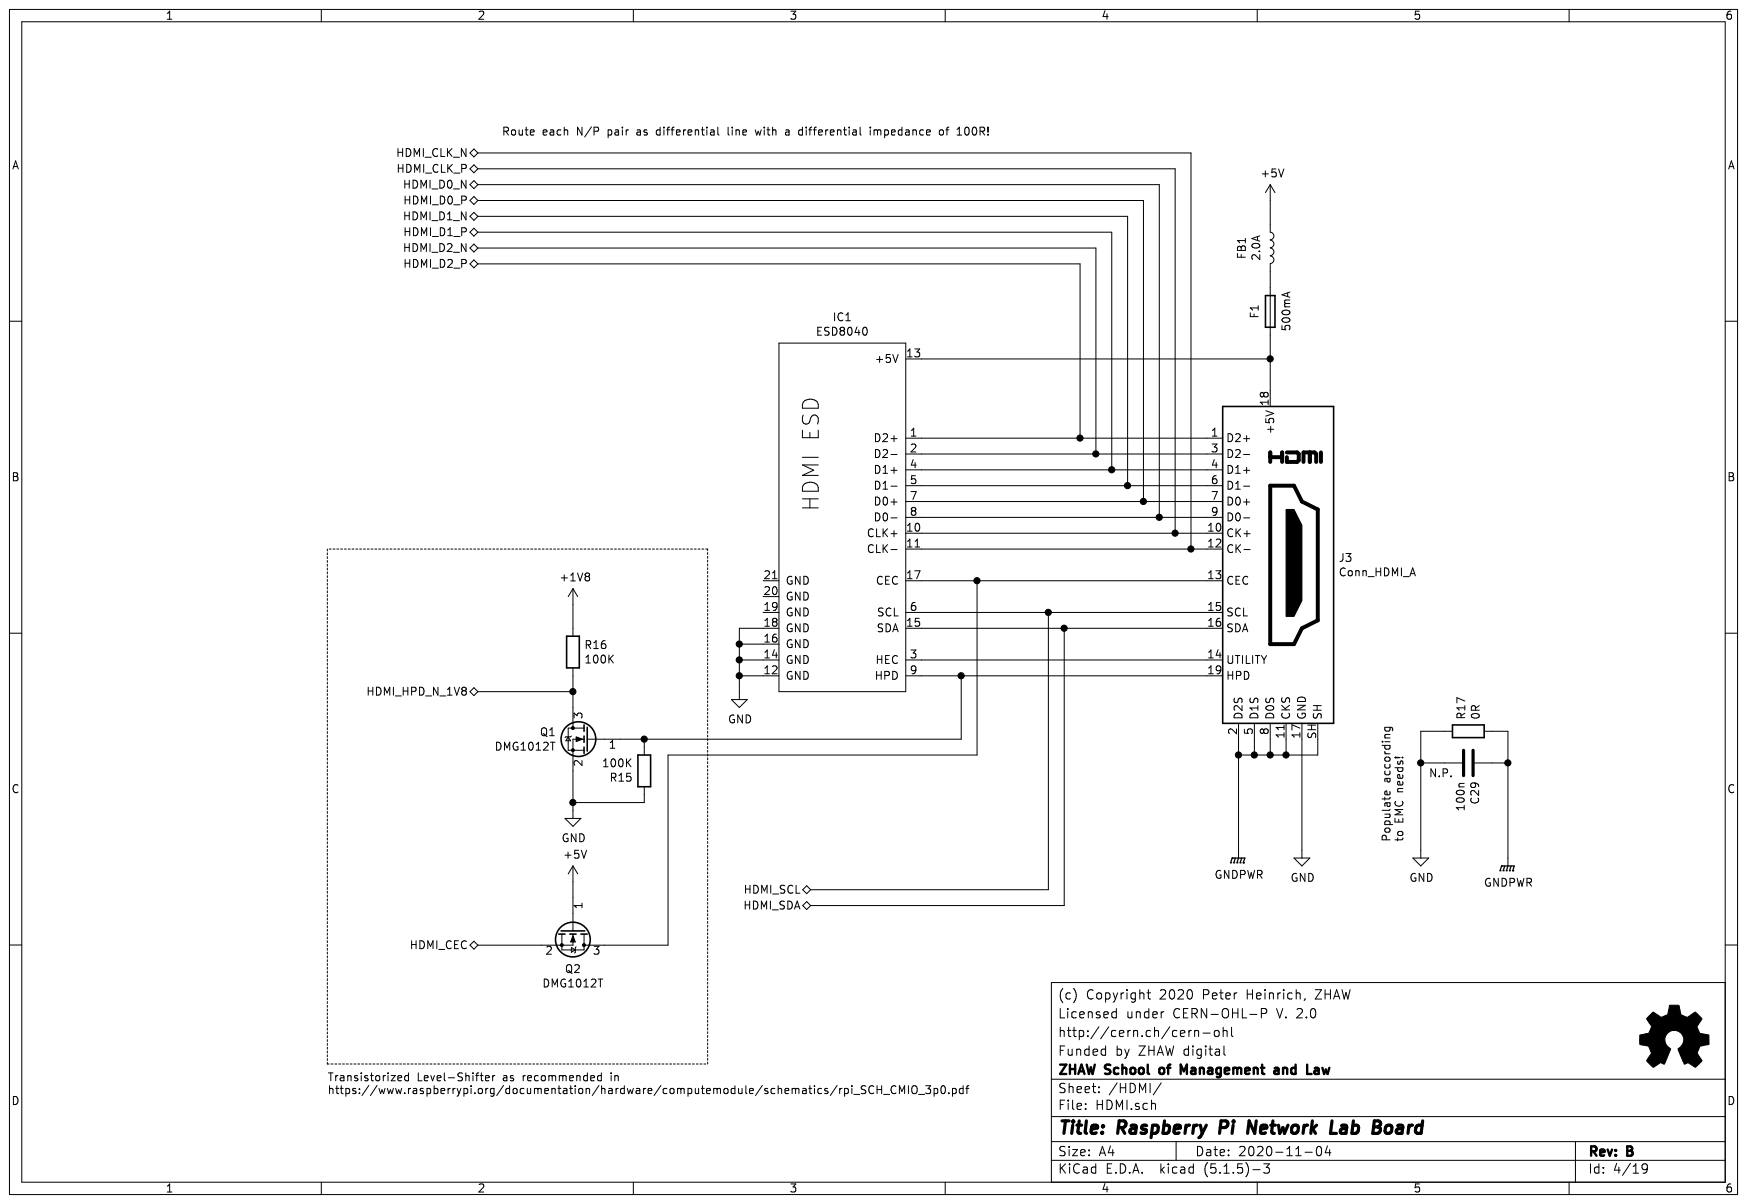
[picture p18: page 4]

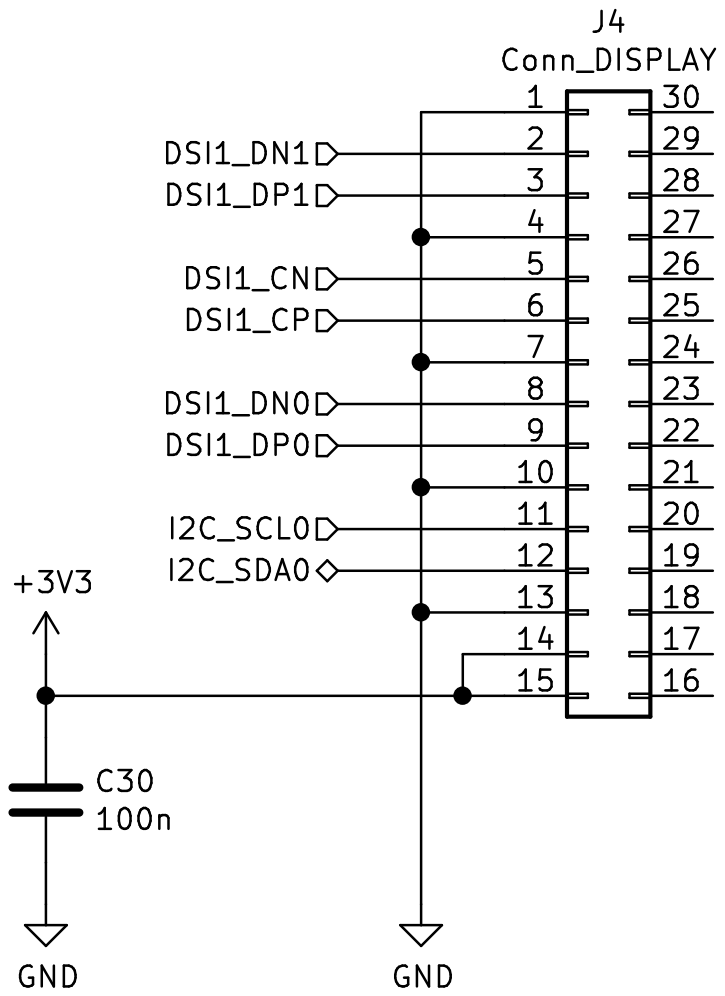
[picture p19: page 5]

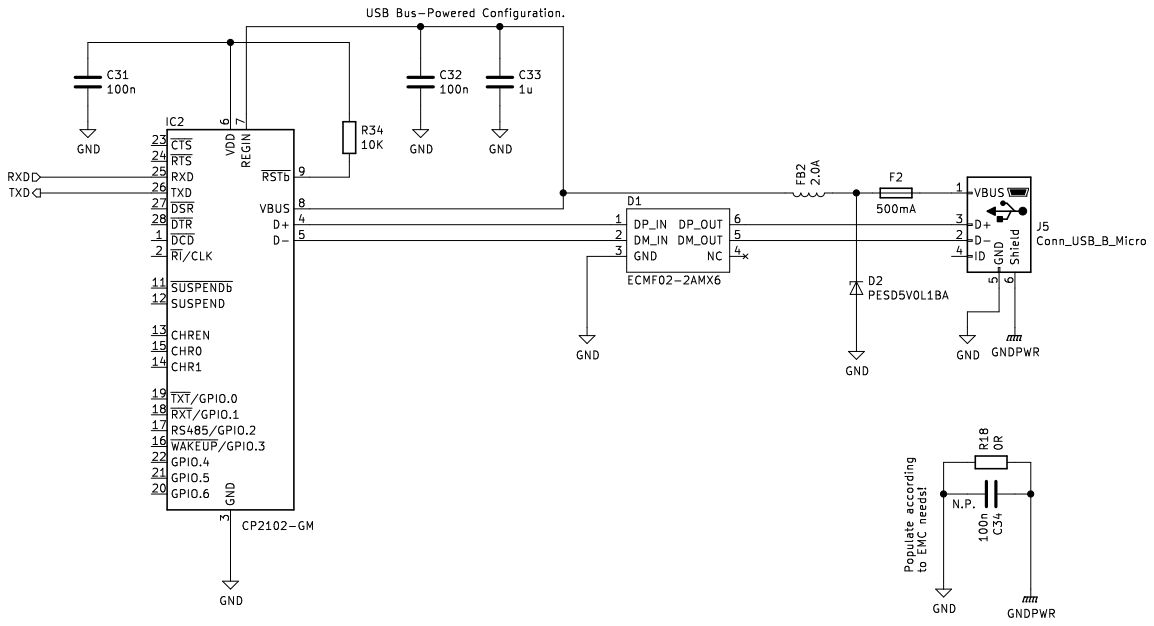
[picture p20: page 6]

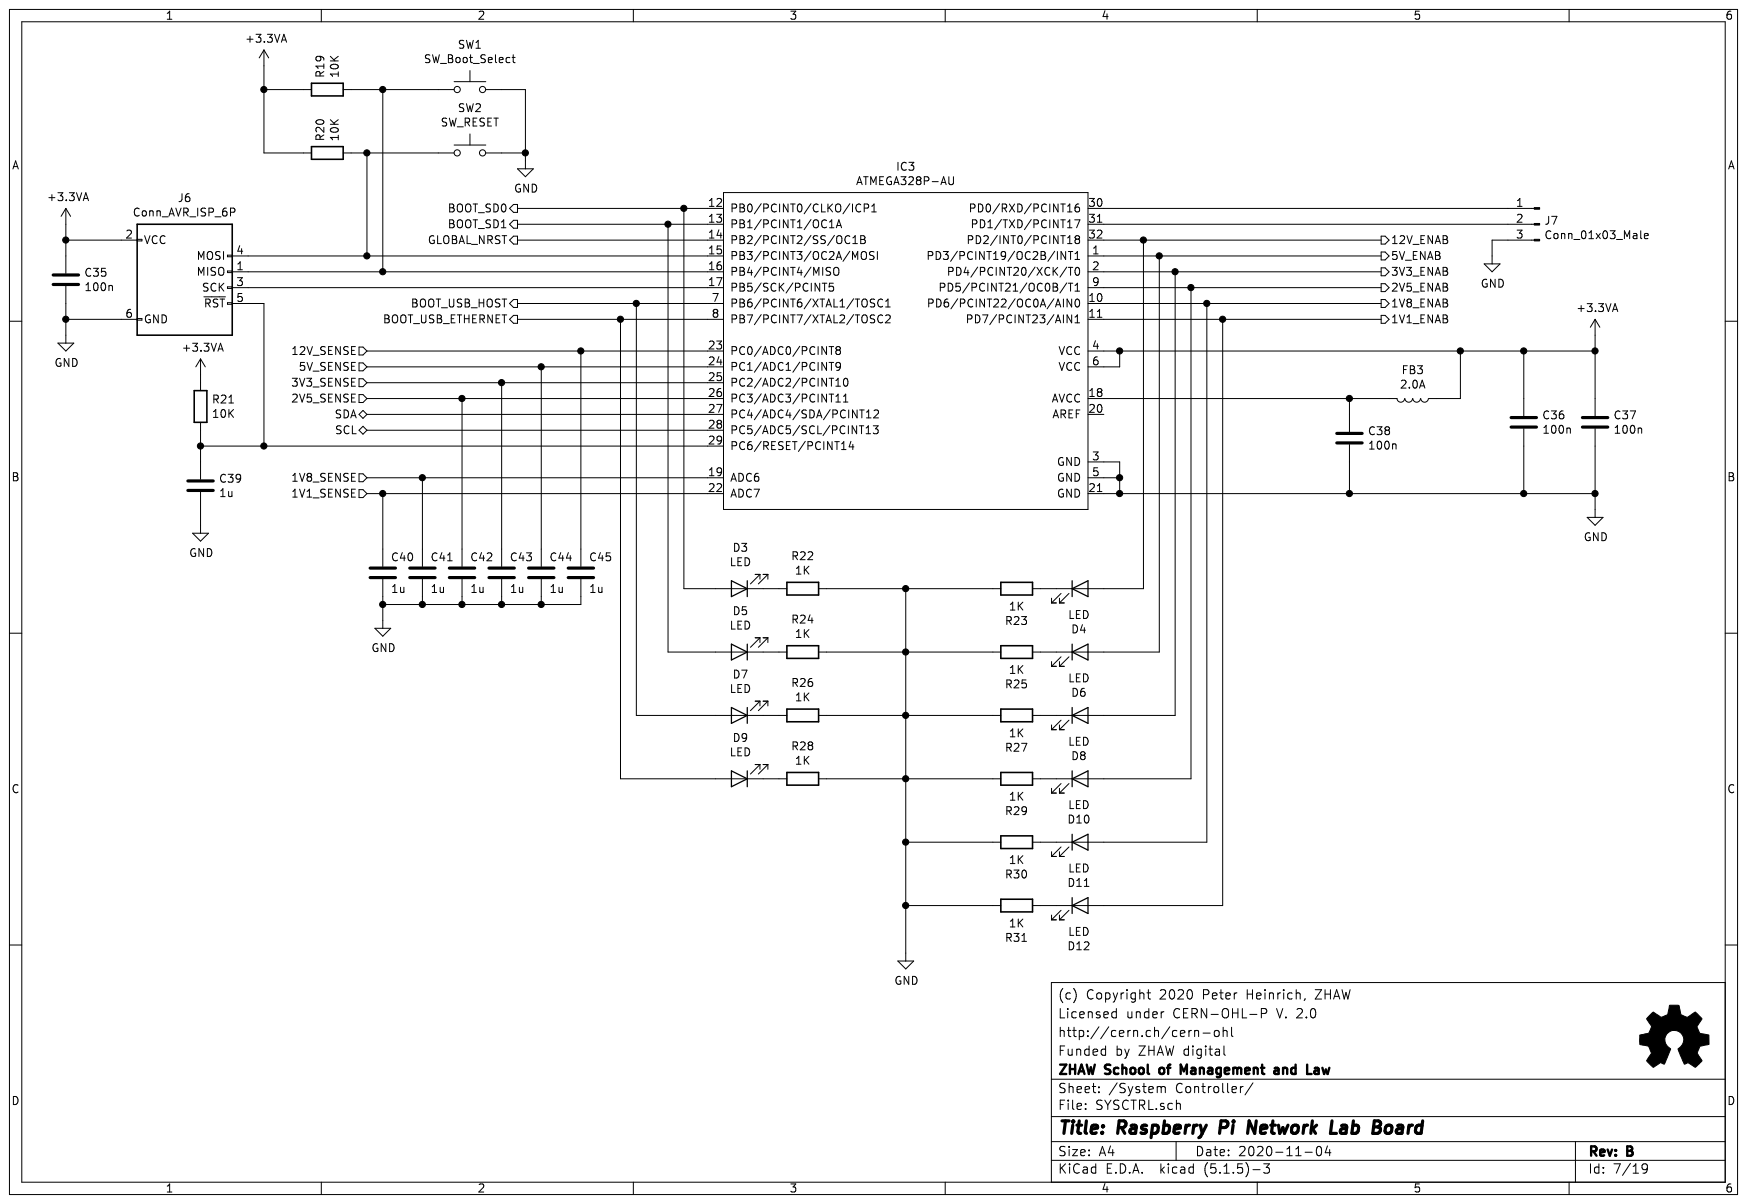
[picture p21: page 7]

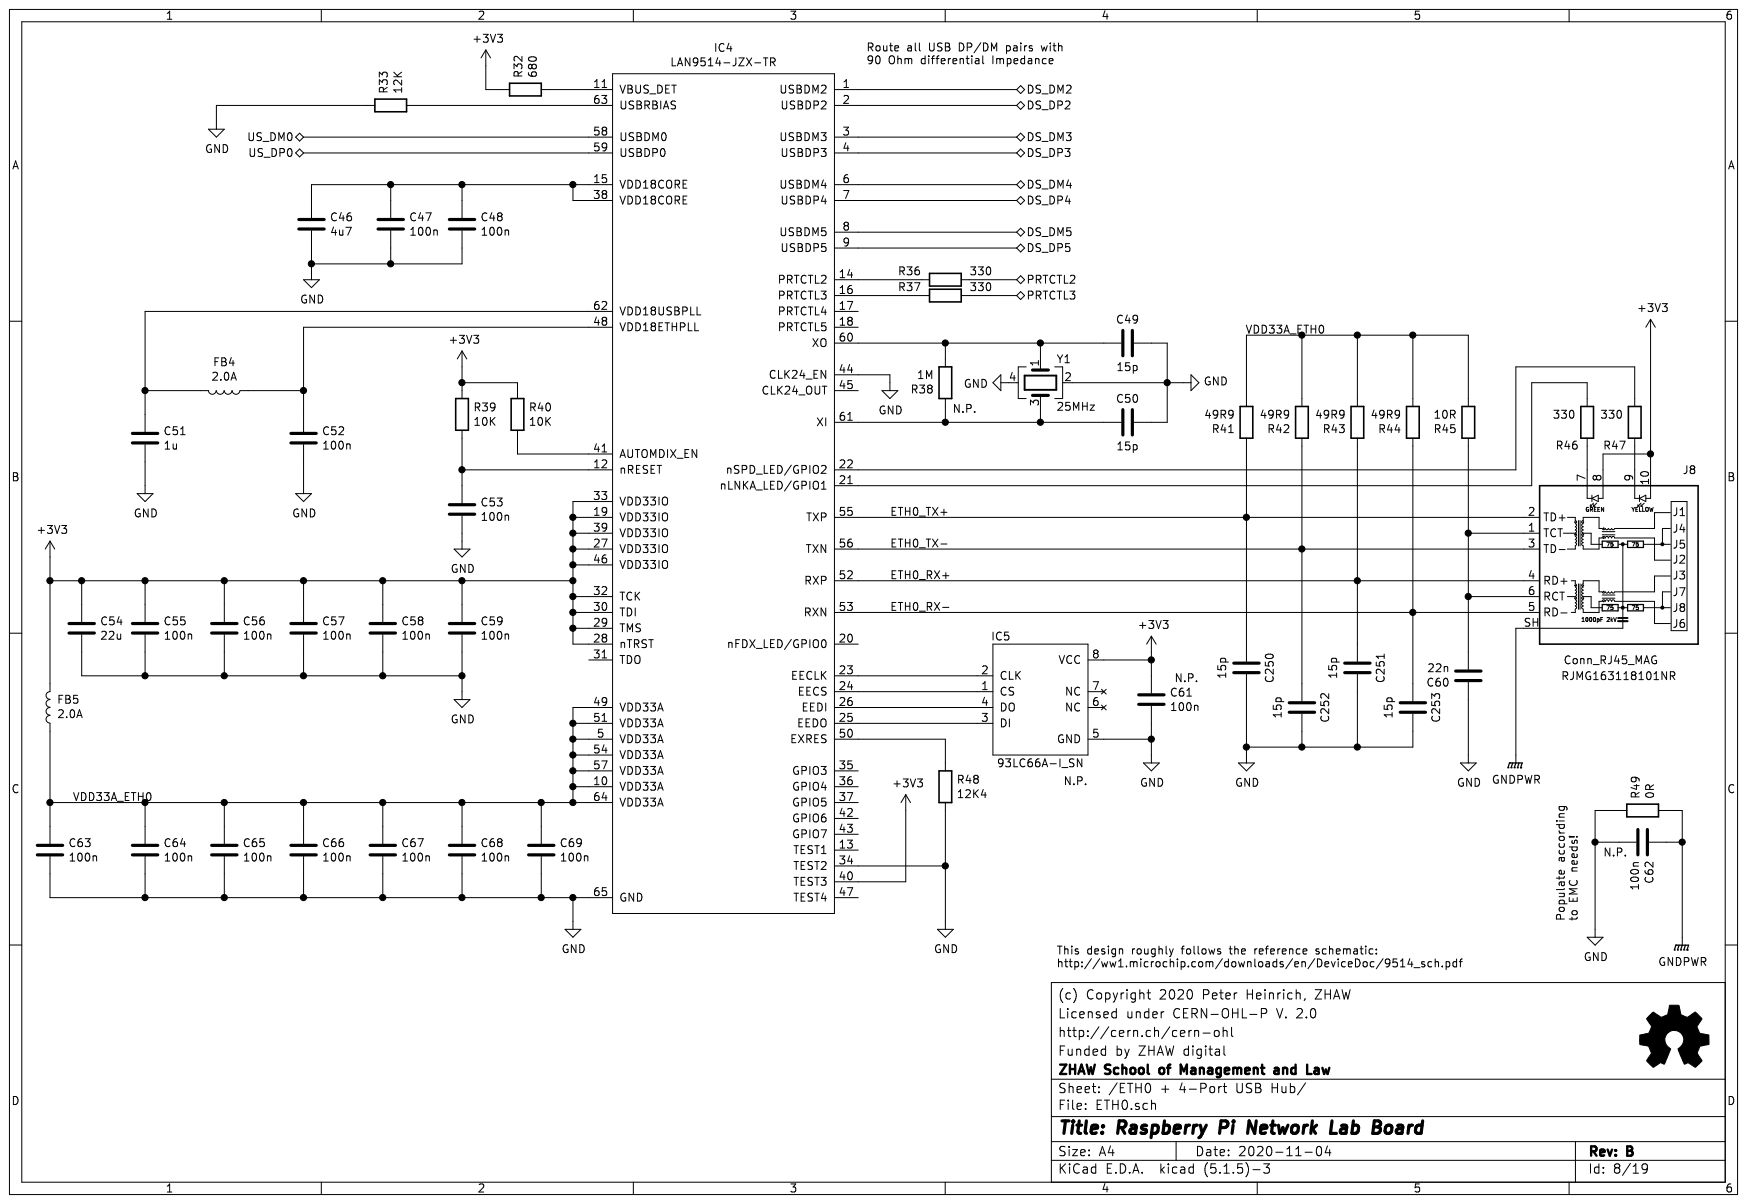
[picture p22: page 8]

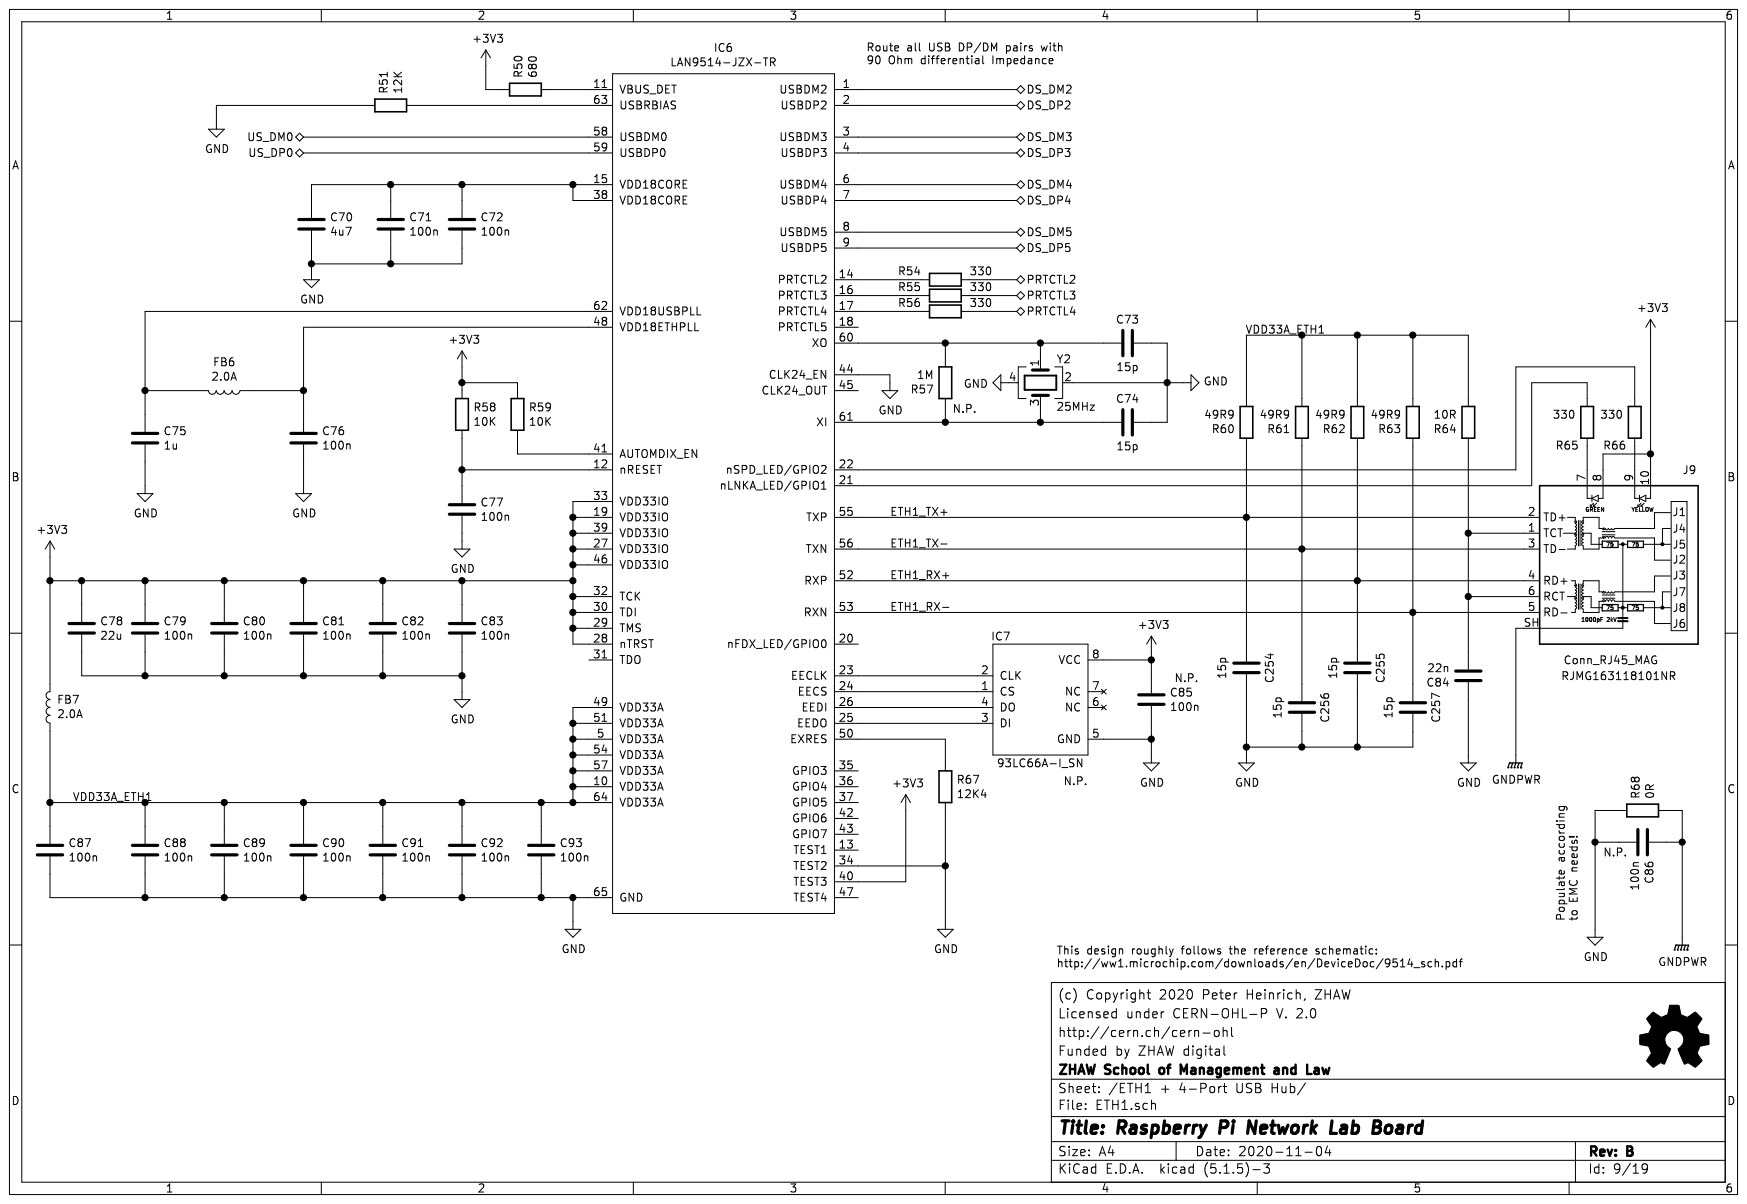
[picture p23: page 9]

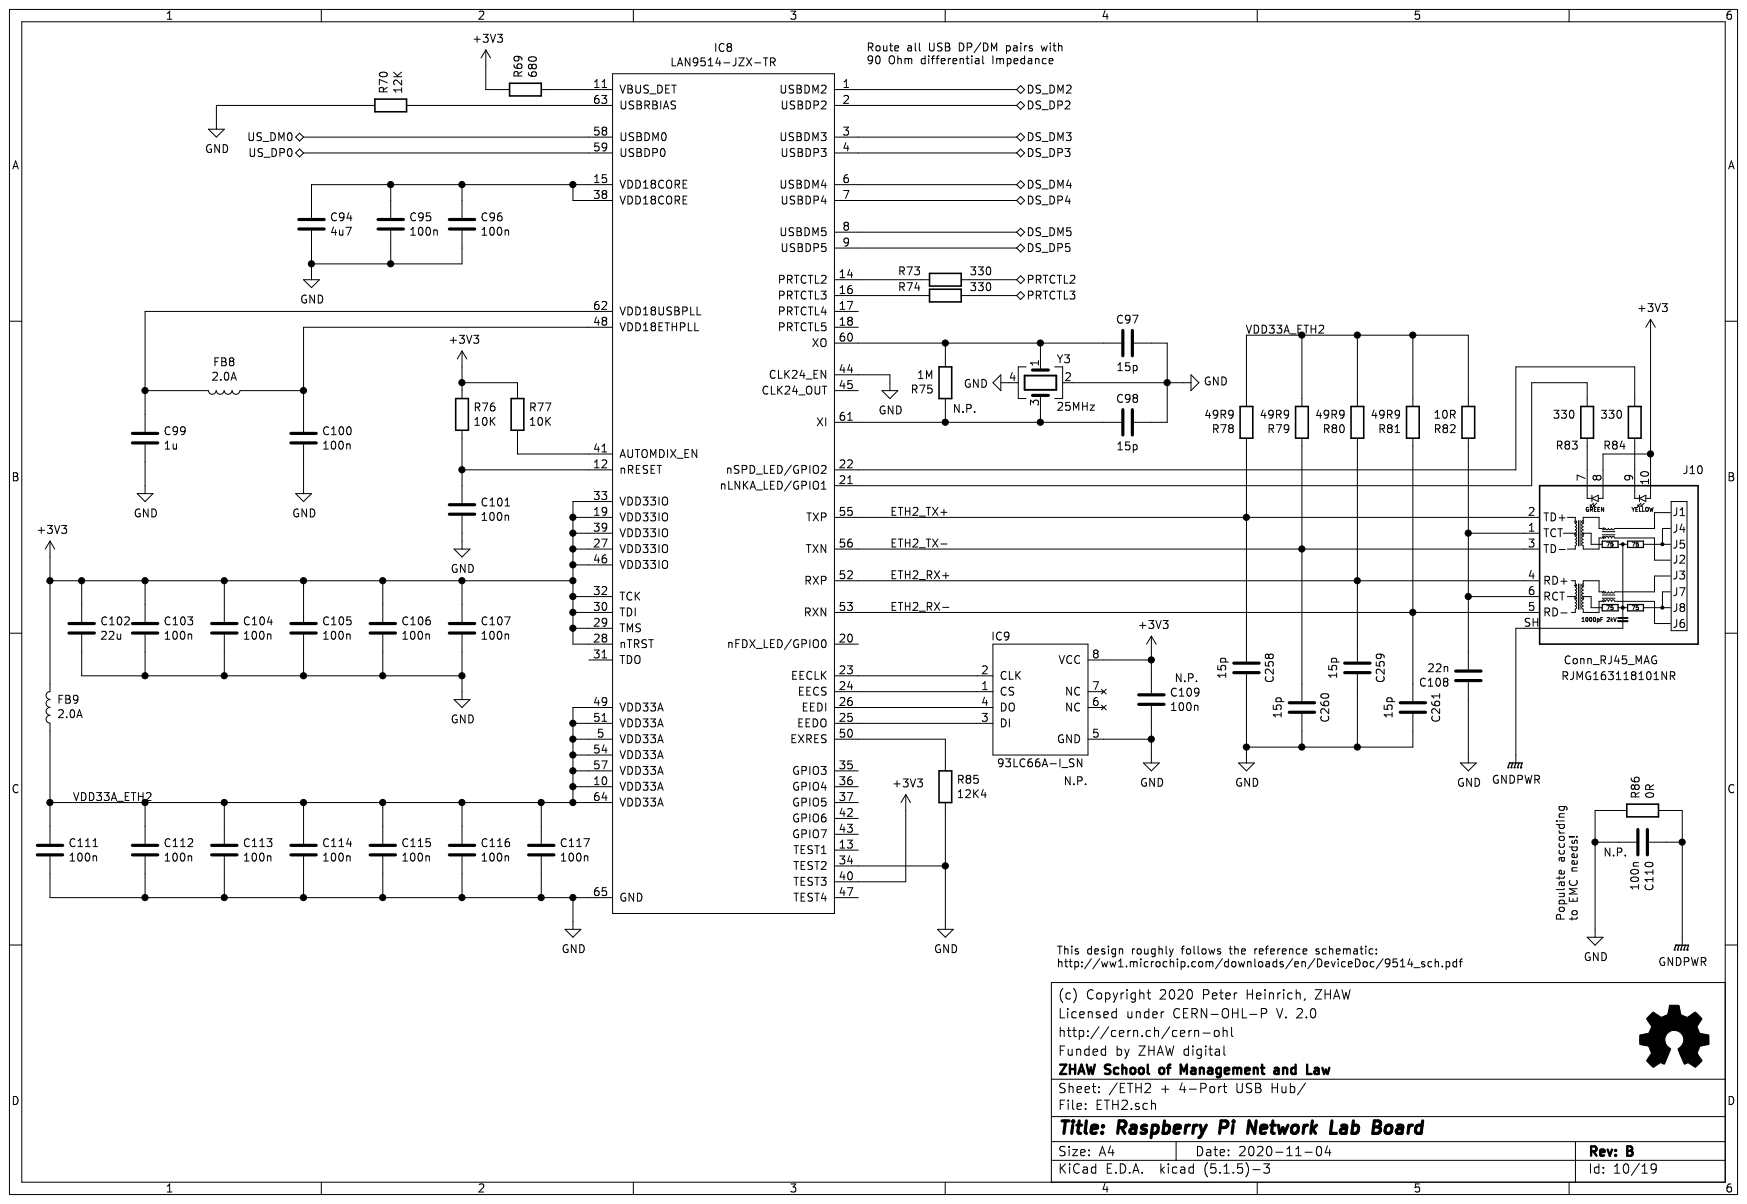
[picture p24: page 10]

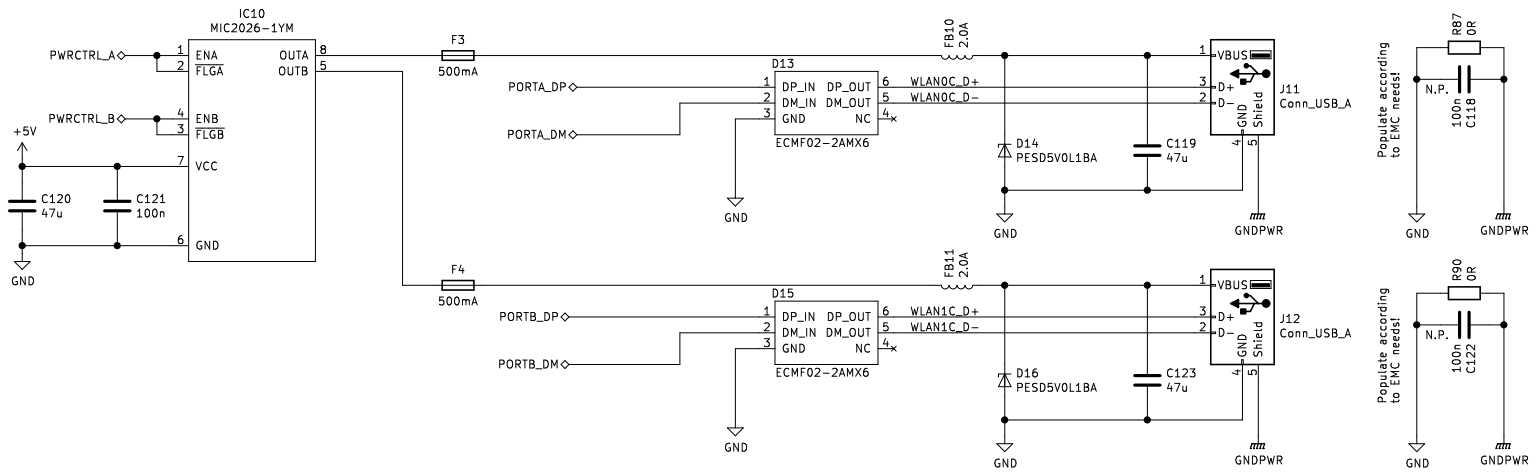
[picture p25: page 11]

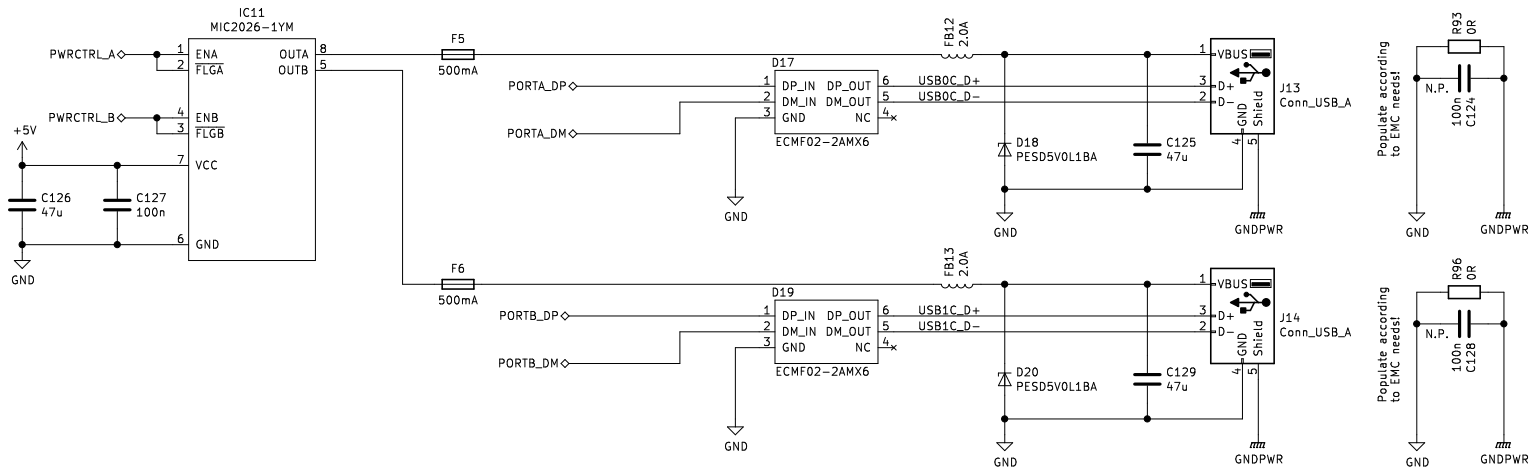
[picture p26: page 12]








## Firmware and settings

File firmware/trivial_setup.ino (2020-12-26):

/*
Copyright (c) 2020, Peter Heinrich, ZHAW

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
1. Redistributions of source code must retain the above copyright notice, this
   list of conditions and the following disclaimer.

2. Redistributions in binary form must reproduce the above copyright notice,
   this list of conditions and the following disclaimer in the documentation
   and/or other materials provided with the distribution.

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
*/

#define BOOT_SD0 8
#define SIG_12V_ENAB 2
#define SIG_5V_ENAB 3
#define SIG_3V3_ENAB 4
#define SIG_2V5_ENAB 5
#define SIG_1V8_ENAB 6
#define SIG_1V1_ENAB 7

void setup() {
  pinMode(BOOT_SD0, OUTPUT);
  pinMode(SIG_12V_ENAB, OUTPUT);
  pinMode(SIG_5V_ENAB, OUTPUT);
  pinMode(SIG_3V3_ENAB, OUTPUT);
  pinMode(SIG_2V5_ENAB, OUTPUT);
  pinMode(SIG_1V8_ENAB, OUTPUT);
  pinMode(SIG_1V1_ENAB, OUTPUT);
 
  digitalWrite(SIG_5V_ENAB, HIGH);
  delay(1); 
  digitalWrite(SIG_1V1_ENAB, HIGH);
  digitalWrite(SIG_3V3_ENAB, HIGH);
  delay(1); 
  digitalWrite(SIG_2V5_ENAB, HIGH);
  delay(1); 
  digitalWrite(SIG_1V8_ENAB, HIGH);
  delay(1); 
  digitalWrite(SIG_1V1_ENAB, HIGH);
  delay(1); 
  digitalWrite(SIG_12V_ENAB, HIGH);
}

void loop() {
  digitalWrite(BOOT_SD0, HIGH);
  delay(1000); 
  digitalWrite(BOOT_SD0, LOW);
  delay(1000); 
}

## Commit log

2020-12-07 Initial Project Commit - Proof-of-Concept Rev B
    [DSI.sch, ETH0.sch, ETH1.sch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]
2020-12-07 Fixing Schematic Annotation
    [SATA0.sch, SATA1.sch]
